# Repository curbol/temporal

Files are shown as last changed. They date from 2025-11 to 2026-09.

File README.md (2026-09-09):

# Temporal



A 36-42 key split ergonomic keyboard with wireless support, a breakoff pinky column, and optional encoders in the thumb cluster.

Temporal Preview

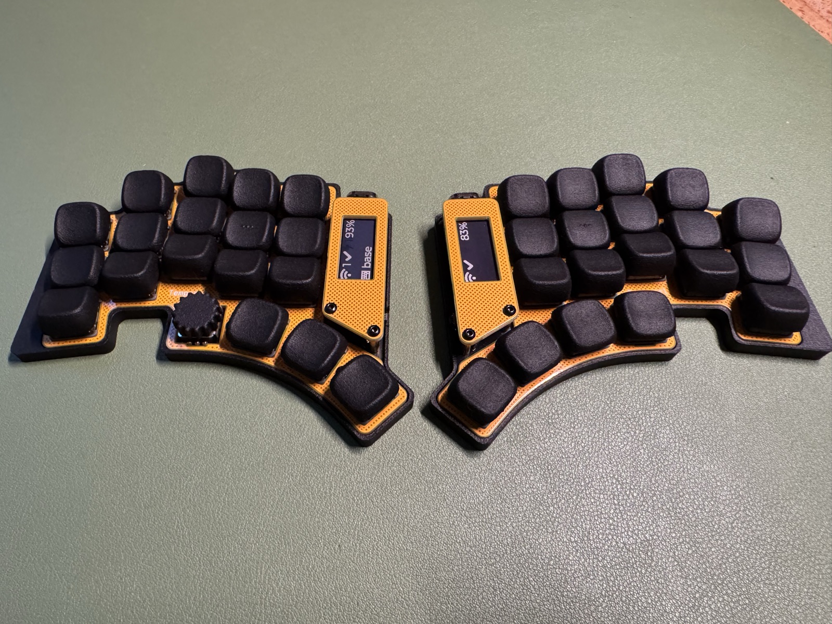
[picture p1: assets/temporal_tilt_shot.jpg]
Temporal tilt shot

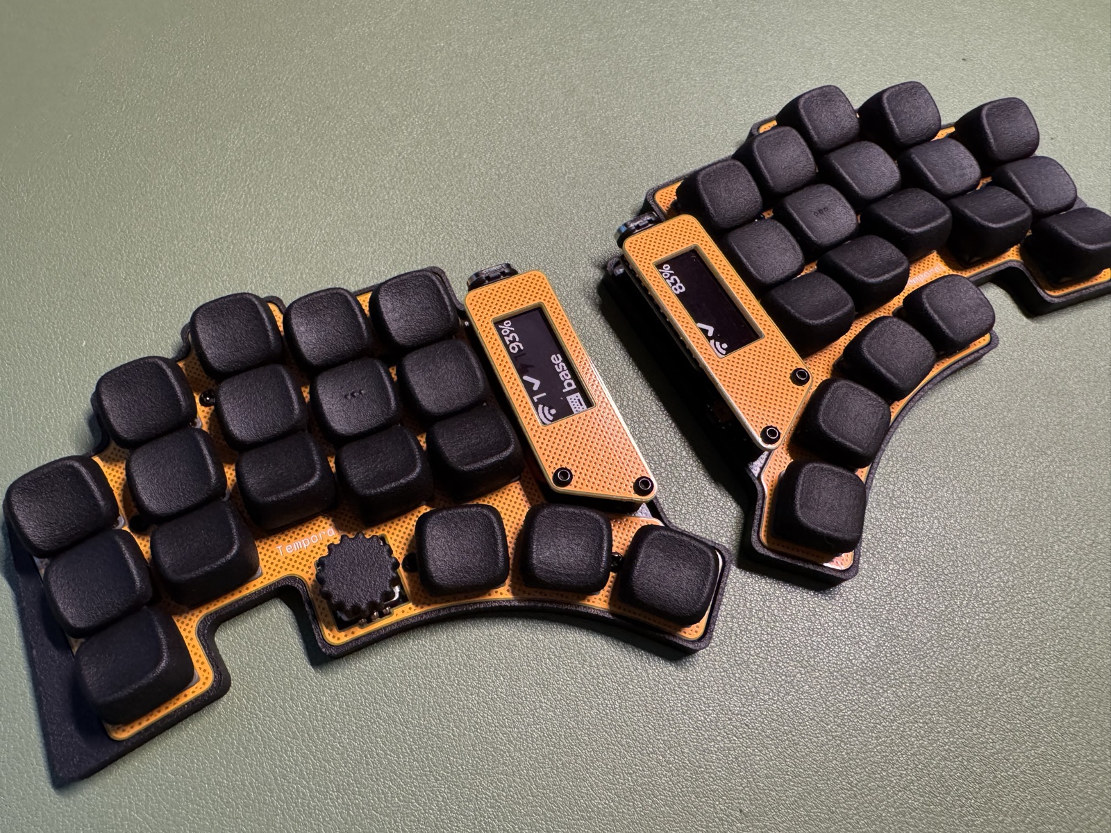
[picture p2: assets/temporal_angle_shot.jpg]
Temporal angle shot


## Design

### Layout

- 36-42 keys depending on configuration:
  - 42/41/40 keys (0/1/2 encoders) with full pinky column
  - 38/37/36 keys (0/1/2 encoders) with breakoff pinky column
- Column stagger and splay on pinky and ring columns

### Hardware

- Kailh Choc v1 or v2 low-profile switches, with optional hotswap sockets
- nice!nano or other Pro Micro compatible microcontrollers
- Optional nice!view display
- Optional EC11/EC12 rotary encoders in thumb cluster (up to 2)
- Wireless with battery support
- Reversible PCB
- 3D-printable cases, with an optional kickstand for tenting

### Tools

- [Ergogen](https://ergogen.ceoloide.com/) generates the layout, PCB, plates, and cases from [ergogen/config.yaml](ergogen/config.yaml)
- [KiCad](https://www.kicad.org/) v10 holds the hand-routed traces; its `pcbnew` API and `kicad-cli` drive the scripted post-processing and the exports

## Firmware

Temporal runs [ZMK](https://zmk.dev/). The shield definition and default keymap live in [temporal-zmk](https://github.com/curbol/temporal-zmk); [curbol/zmk-config](https://github.com/curbol/zmk-config) is a working config that uses it.

## Build Guide

[docs/build-guide.md](docs/build-guide.md) covers assembly and ordering. [docs/bom.md](docs/bom.md) lists every component a full build needs.

## Keycaps

Any Choc-compatible keycap fits. [KLP Lame Keycaps](https://github.com/braindefender/KLP-Lame-Keycaps) are 3D-printable and sculpted; [docs/bom.md](docs/bom.md#switches--keycaps) lists the print quantities for a full build.

## Development

### Prerequisites

- Node.js and npm
- A package manager `make deps` can drive: [Homebrew](https://brew.sh/) on macOS, or `pacman` and `yay` on Arch Linux

### Setup

1. Install dependencies (OpenSCAD, KiCad, zip/unzip, [Maple Mono NF](https://github.com/subframe7536/maple-font) font, and KiCad plugins):

```bash
make deps
```

2. Generate PCBs and cases:

```bash
make gen
```

This will:

- Run Ergogen to generate PCB and case files
- Derive `temporal.json`, the ZMK Studio physical layout, from the same points
- Post-process PCBs (edge cuts, silkscreen widths, ground planes, text keepouts,
  via stitching, zone fills, embedded fonts)
- Configure KiCad project files with defaults from `scripts/kicad_config.yaml`
- Derive the `top_plate_*_stealth` variants from the generated top plates
- Render `assets/preview.svg` and a `pcb.png` per board
- Export gerbers for manufacturing
- Generate the JLCPCB BOM and CPL files in `jlcpcb/`
- Generate STL case files

**Note:** The main `pcbs/temporal/` PCB requires manual steps in KiCad after generation. See [pcbs/temporal/README.md](pcbs/temporal/README.md) for details.

### Verifying

```bash
make check
```

Confirms the sources parse and lint, `ergogen/config.yaml` builds, every committed board passes DRC and carries its own silkscreen font, and the pours in `pcbs/` still match the custom DRC rules and the zone settings. It then regenerates each committed derived artifact and diffs it against what is checked in: `temporal.json`, `jlcpcb/`, the `.kicad_pro` and `.kicad_dru` files, the `top_plate_*_stealth` boards, and the gerber zips. This is what CI runs on every push.

## Influences

Temporal takes influence from:

- [Hillside](https://github.com/mmccoyd/hillside) by mmccoyd
- [TOTEM](https://github.com/GEIGEIGEIST/TOTEM) and [KLOR](https://github.com/GEIGEIGEIST/KLOR) by GEIST
- [TEMPEST](https://github.com/thrly/tempest) by thrly

## Support



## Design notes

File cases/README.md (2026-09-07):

# Cases

3D-printable parts. The STLs here are generated from
[`ergogen/config.yaml`](../ergogen/config.yaml) by `make gen`; edit the config, not
these files. This README is the one thing in the folder `make clean` keeps.

```
cases/
├── mcu_cover.stl
├── 38/
│   ├── top_plate.stl
│   ├── left.stl            right.stl
│   └── kickstand_left.stl  kickstand_right.stl
└── 42/                     (same layout)
```

## What to print

| part | quantity | notes |
|---|---|---|
| `NN/left.stl` and `NN/right.stl` | 1 each | the case halves, or the `kickstand_` pair instead |
| `NN/top_plate.stl` | 2 | one file, printed twice and flipped for the second hand |
| `mcu_cover.stl` | 2 | shared by both key counts |

`NN` is your key count: `42` if you keep the full pinky column, `38` if you snap it off.
A `42` case also fits the 41 and 40-key encoder configurations, and a `38` case the 37
and 36. Print the plain pair or the `kickstand_` pair, not both; the kickstand is a wedge
fused to the case for tenting.

[The build guide](../docs/build-guide.md#choose-your-build) walks through this alongside
the PCB and plate choices, and [docs/bom.md](../docs/bom.md) lists the hardware.

## One case, every build

There is no variant to choose. The case carries the clearances for all four switch and
mounting combinations at once:

- Choc v1 centre and side posts
- the Choc v2 centre boss and its corner stabilizer pin
- hotswap sockets, which stand 1.95mm off the back of the PCB
- the pins of switches soldered straight to the board

The floor is 2.35mm, which is the socket depth plus a 0.4mm skin. That makes every one
of those pockets blind, so the bottom face is solid and none of them shows through.

Print the halves bottom-down. Every pocket opens upward, so nothing needs support.

## FR-4 alternative

The top plate and MCU cover also exist as orderable PCBs
([`gerbers/`](../gerbers/)), and there is an FR-4 back plate that replaces the printed
case entirely, held off the board by 3mm standoffs. See
[the build guide](../docs/build-guide.md#fr-4-plate-alternative).

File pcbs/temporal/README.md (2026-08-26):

# Temporal PCB

`make gen` never overwrites this directory.

## Why

This board is hand-routed in KiCad, and the traces and vias here cannot be
regenerated. The build leaves the `.kicad_pcb` alone and rewrites only the
`.kicad_pro` and `.kicad_dru` beside it.

## How to Regenerate

Delete the folder, then rebuild:

```bash
rm -rf pcbs/temporal
make gen
```

That recreates the directory and a fresh, unrouted board from
`ergogen/config.yaml`.

## Manual Steps in KiCad

After regenerating, route the connections Ergogen does not place. Ground planes,
silkscreen text keepouts, via stitching, and zone fills are all applied by
`make gen` before the board is copied here, so they need no manual work.

## Keeping This Board Current

The post-processing steps run against `ergogen/output/pcbs`, so they reach this
board only when it is regenerated. Editing the `zones`, `via_stitching`, or
`text_keepouts` sections of `scripts/kicad_config.yaml` updates every other board
and leaves this one as it was. `make check` fails when the pour no longer matches
the custom DRC rules; a via stitching or keepout change needs a full regeneration
and a re-route.

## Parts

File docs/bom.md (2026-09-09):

# Bill of Materials (BOM)

Everything needed to build one Temporal keyboard, both halves.

## Required Components

### Electronics

| Component | Quantity | Notes | Source | Image |
|---|---|---|---|---|
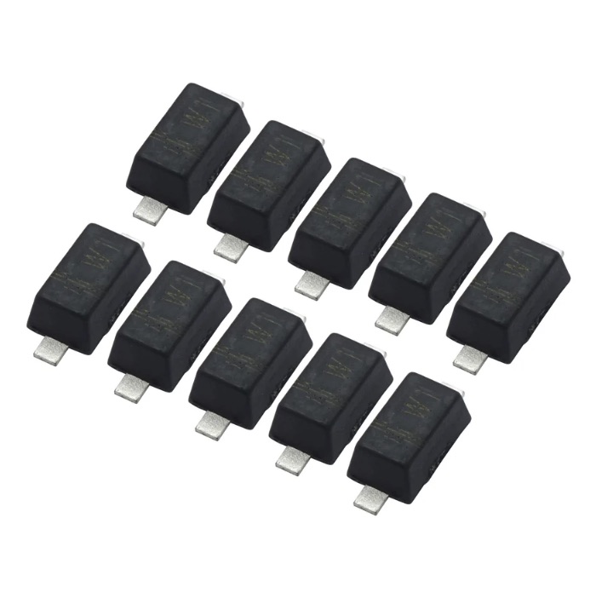
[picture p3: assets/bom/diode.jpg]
SMD diode
| SMD Diodes (1N4148W) | 36-42 | One per switch, depends on configuration (not needed if using JLCPCB assembly) | [KEEBD](https://keebd.com/) [Typeractive](https://typeractive.xyz/) |  |
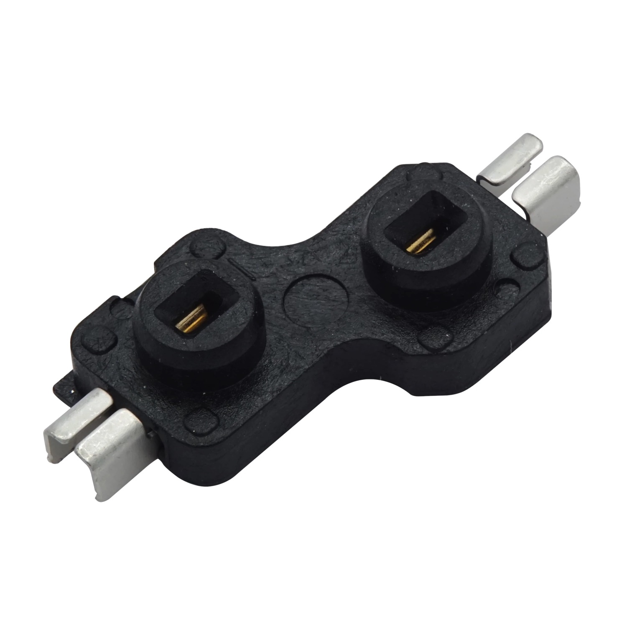
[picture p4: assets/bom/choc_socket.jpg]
Choc socket
| Kailh Choc Hotswap Sockets | 36-42 | Optional; allows switch swapping without desoldering | [KEEBD](https://keebd.com/) [Typeractive](https://typeractive.xyz/) |  |
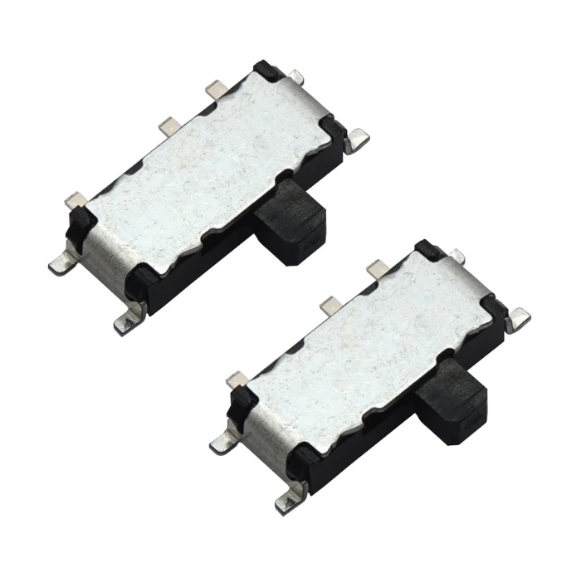
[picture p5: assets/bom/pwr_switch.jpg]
Power switch
| Power Switch (MSK12C02) | 2 | Power on/off switch | [KEEBD](https://keebd.com/) [Typeractive](https://typeractive.xyz/) |  |
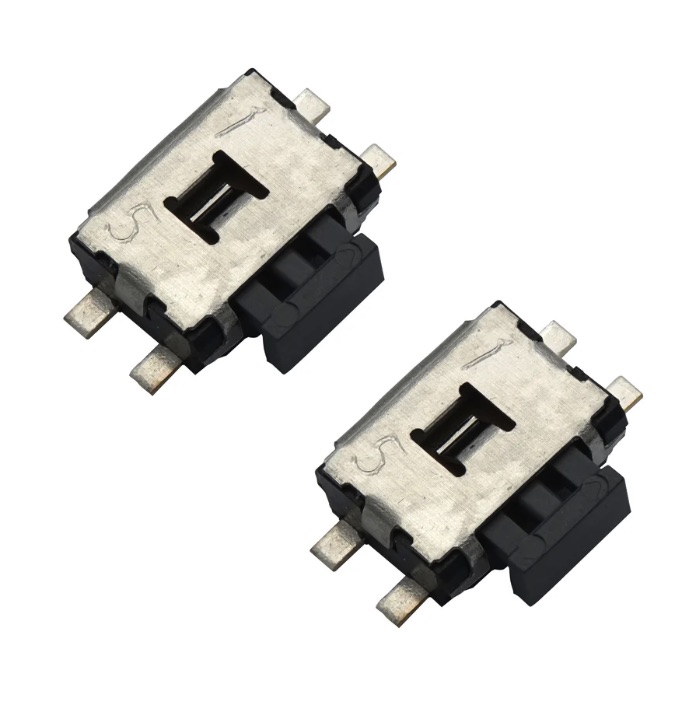
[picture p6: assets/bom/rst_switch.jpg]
Reset switch
| Reset Button (3x6x4.3mm) | 2 | SMD tactile switch | [KEEBD](https://keebd.com/) [Typeractive](https://typeractive.xyz/) |  |
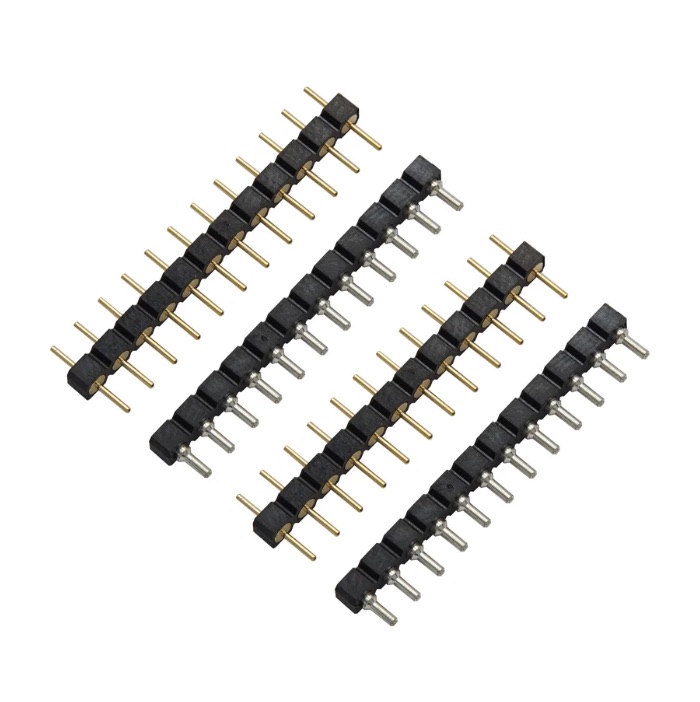
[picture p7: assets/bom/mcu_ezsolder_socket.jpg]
EZ-Solder sockets
| EZ-Solder Machine Sockets and Headers | 2 sets | For nice!nano installation | [KEEBD](https://keebd.com/) [Typeractive](https://typeractive.xyz/) |  |
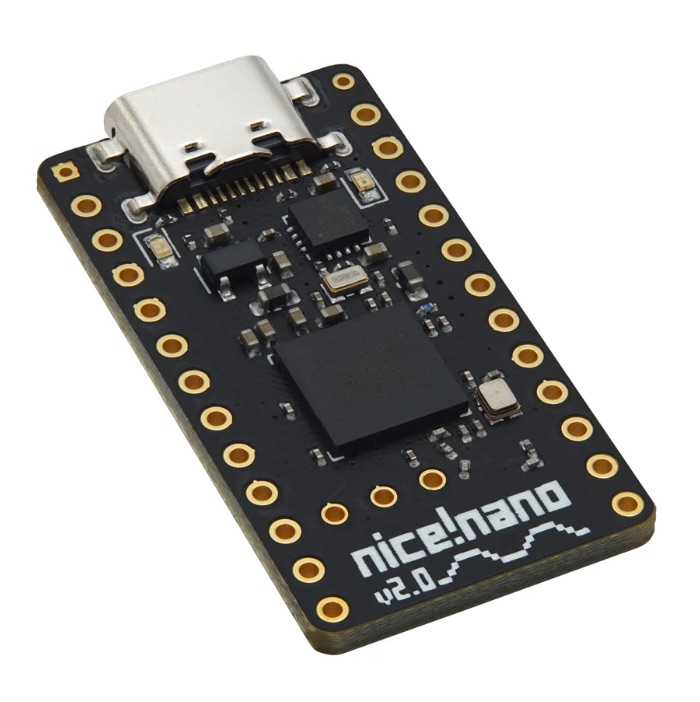
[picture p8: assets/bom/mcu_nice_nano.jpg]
nice!nano
| nice!nano v2.0 | 2 | Wireless microcontroller | [KEEBD](https://keebd.com/) [Typeractive](https://typeractive.xyz/) |  |
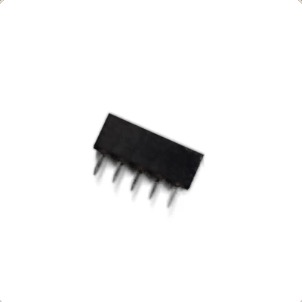
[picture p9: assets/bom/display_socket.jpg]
Display socket
| Display Header Socket (5-pin 2.54mm) | 2 | If your display doesn't already come with the correct header | [KEEBD](https://keebd.com/) [Typeractive](https://typeractive.xyz/) |  |
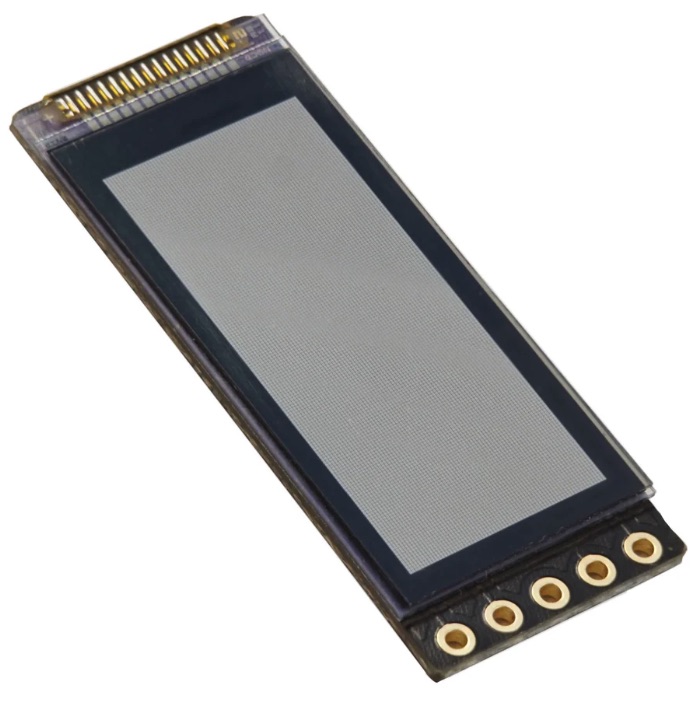
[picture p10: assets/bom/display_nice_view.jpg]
nice!view
| nice!view | 2 | Optional display | [KEEBD](https://keebd.com/) [Typeractive](https://typeractive.xyz/) |  |
| Battery Jack (JST PH 2.0mm) | 2 | For battery connection | [KEEBD](https://keebd.com/) [Typeractive](https://typeractive.xyz/) | Battery connector |
| Lithium Battery 110mAh | 2 | PH 2.0mm connector (or similar capacity) | [KEEBD](https://keebd.com/) [Typeractive](https://typeractive.xyz/) | Battery |
| ALPS EC11/EC12 Rotary Encoder | 0-2 | Optional, for thumb key encoder positions | [KEEBD](https://keebd.com/en-us/collections/components) | Encoder |
| Low Profile Knurled Encoder Knob | 0-2 | If using encoders | [KEEBD](https://keebd.com/en-us/collections/components) | Encoder knob |

Encoders and hotswap sockets are both optional: regular switches work in the encoder positions, and switches can be soldered straight to the PCB.

### Hardware

| Component | Quantity | Notes | Source | Image |
|---|---|---|---|---|
| M2 Heat-Set Inserts | 10 | 3mm OD × 3mm height (2mm height also works) | [KEEBD](https://keebd.com/) | Heat-set insert |
| M2 Screws (4mm length) | 18 | Button-head recommended | Amazon | M2 screw |
| M2 Standoffs (8mm length) | 4 | For MCU cover mounting | [KEEBD](https://keebd.com/) Amazon | M2 standoff |
| M2 Standoffs (3mm length) | 10 | FR-4 plate build only, in place of the heat-set inserts | Amazon | |
| M2 Screws (3mm length) | 20 | FR-4 plate build only, button-head | Amazon | |

Avoid inserts wider than 3mm OD. A 3.2mm insert may not seat in the case posts.

### Switches & Keycaps

| Component | Quantity | Notes | Source | Image |
|---|---|---|---|---|
| Choc v1 or v2 Switches | 36-42 | Low-profile switches, depends on configuration | [Low Pro KB](https://lowprokb.ca/) [KEEBD](https://keebd.com/en-us/collections/choc-switches) | Choc switch |
| Choc Keycaps | 36-42 | Compatible with Choc switches | | |

[Ambients Silent Choc switches](https://lowprokb.ca/collections/switches/products/ambients-silent-choc-switches) are my pick for a quiet, smooth feel. Sculpted keycaps improve the feel more than anything else on this page, though that is personal preference.

[KLP Lame Keycaps](https://github.com/braindefender/KLP-Lame-Keycaps) are 3D-printable sculpted keycaps for Choc switches. Ordered from a printing service, a full Temporal build needs:

| Part | Quantity | Contents |
|---|---|---|
| Saddle part 1 | 1 | 6 tilted, 3 saddle |
| Saddle part 2 | 2 | 4 tilted, 4 saddle, 1 homing |
| Saddle part 3 | 1 | 9 tilted |
| Thumbs | 1 | 9 thumbs |

Totals: 23 tilted, 11 saddle, 2 homing, and 9 thumb, of which 6-8 are used depending on encoders.

### PCBs & Cases

| Component | Quantity | Notes |
|---|---|---|
| Temporal PCB | 2 | Order using `gerbers/temporal.zip` |
| 3D-Printed Case (Left) | 1 | Choose your key configuration and switch mounting (see below) |
| 3D-Printed Case (Right) | 1 | Choose your key configuration and switch mounting (see below) |
| MCU Cover | 2 | Optional, protects the microcontroller |

Use [`gerbers/temporal.zip`](/gerbers/temporal.zip) for PCB fabrication with services like JLCPCB or PCBWay.

- Material: FR-4, 1.6mm thickness
- Surface finish: LeadFree HASL
- See [`pcbs/temporal/README.md`](/pcbs/temporal/README.md) for notes on the hand-routed main PCB

> [!TIP]
> Top plates, back plates, and MCU covers can be ordered in HASL (with lead) instead of LeadFree HASL. It is usually cheaper, and these parts have no exposed copper pads, so the finish does not matter.

> [!TIP]
> Order top plates at 1.2mm thickness instead of 1.6mm for the best fit with Choc switches.

3D-printable case files are in the [`cases/`](/cases/) directory, foldered by key count:

```
cases/
├── mcu_cover.stl
├── 38/
│   ├── top_plate.stl
│   ├── left.stl            right.stl
│   └── kickstand_left.stl  kickstand_right.stl
└── 42/                     (same layout)
```

Pick your key count, then print the `left` and `right` pair, with or without the
kickstand. One case fits every build: Choc v1 or v2, hotswap sockets or switches
soldered straight to the board. It carries the clearances for all of them, and at a
2.35mm floor every pocket is blind, so the bottom face is solid.

- **`38` / `42`**: key configuration, matching the breakoff pinky column. A 42 case
  also takes the 41 and 40-key encoder configurations, and a 38 case the 37 and 36.
- **`kickstand`**: optional, adds a wedge for tenting.
- **`top_plate`**: one per hand, printed twice from the same file and flipped.
- **`mcu_cover`**: shared by both hands and both key counts, printed twice.

Top plates are also available as `top_plate_<38|42>_stealth` gerbers: the same plate
without the white silkscreen branding, leaving the lettering as an outline in the
ground plane.

**For home 3D printing:**

- Material: matte PLA
- Layer height: 0.12mm
- Infill: not critical, since the walls are thin

**For JLC's 3D printing service:**

- Technology: MJF (nylon)
- Material: PA11-HP nylon, verified to work well for cases and keycaps

> [!NOTE]
> Other materials likely print fine too; these are just the ones tested.

Alternatively, the gerbers in [`gerbers/`](/gerbers/) cover FR-4 switch plates you can order alongside your PCB: top plates, back plates, and MCU covers for every configuration.

## Optional Tools

| Tool | Purpose | Source | Image |
|---|---|---|---|
| NovelLife Heat-Set Insert Tool | Drives heat-set inserts with a soldering iron | Amazon | Heat-set insert tool |
| Flux Pen | Helps solder flow nicely, especially for jumpers | [KEEBD](https://keebd.com/en-us/products/kester-951-no-clean-solder-flux-pen) | Flux pen |

## Where to Buy

- [KEEBD](https://keebd.com/): nice!nano, nice!view, switches, sockets, encoders, and most other components
- [Typeractive](https://typeractive.xyz/): most of the same parts
- Amazon: heat-set inserts, screws, and general hardware
- AliExpress: cheaper on most components, with longer shipping

### PCB Manufacturing

- [JLCPCB](https://jlcpcb.com/): inexpensive, with an optional assembly service
- [PCBWay](https://www.pcbway.com/): the usual alternative

Use the gerber files in [`gerbers/`](/gerbers/) when ordering.

> [!TIP]
> Here is how JLCPCB's PCB colors look:
>
> PCB color options

#### JLCPCB Assembly (Optional)

JLCPCB can pre-assemble the SMD parts onto your PCBs:

- 21 diodes per board, so none of them need hand-soldering
- 30 0-ohm resistors per board, bridging the solder jumper pads for the MCU, display, and battery connections

To use this service:

1. Select "PCB Assembly" when ordering
2. Upload files from [`jlcpcb/`](/jlcpcb/):
   - `temporal_BOM.csv`: the bill of materials, with LCSC part numbers
   - `temporal_CPL_top.csv`: places parts on the top face, giving the **right**
     half (its top silkscreen reads "Back Right" above the MCU area)
   - `temporal_CPL_bottom.csv`: places parts on the bottom face, giving the
     **left** half ("Back Left")

You need one board of each hand, and assembly is ordered per side, so place two
orders, one per CPL file. A single order using one CPL gives you two identical
halves.

> [!NOTE]
> Hotswap sockets are not in the assembly files, so they still need hand-soldering.

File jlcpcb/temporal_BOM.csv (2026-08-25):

Comment | Designator | Footprint | LCSC Part #
0402 0-Ohm Resistor | JR1,JR10,JR11,JR12,JR13,JR14,JR15,JR16,JR17,JR18,JR19,JR2,JR20,JR21,JR22,JR23,JR24,JR25,JR26,JR27,JR28,JR29,JR3,JR30,JR4,JR5,JR6,JR7,JR8,JR9 | 0402 | C17168
1N4148W Diode SOD-123 | D1,D10,D11,D12,D13,D14,D15,D16,D17,D18,D19,D2,D20,D21,D3,D4,D5,D6,D7,D8,D9 | ceoloide:diode_tht_sod123 | C81598

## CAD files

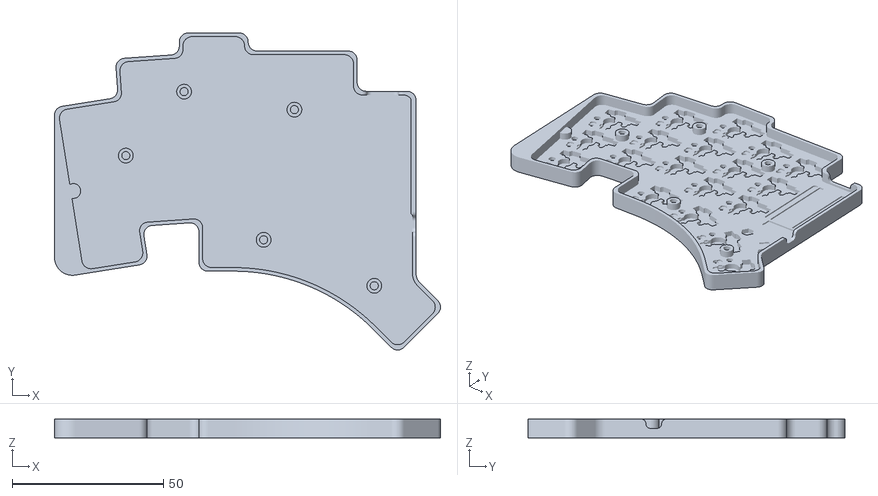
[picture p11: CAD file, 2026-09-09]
cases/38/kickstand_left.stl
127.5 x 104.7 x 6.25

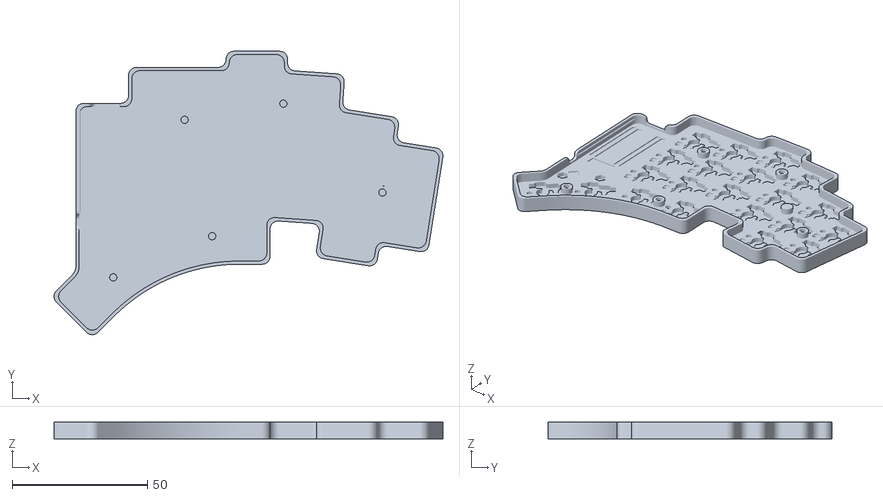
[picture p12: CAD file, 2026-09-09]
cases/42/right.stl
143.7 x 104.7 x 6.25

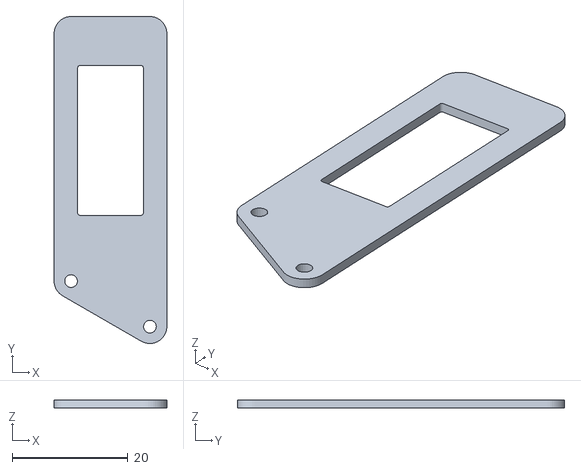
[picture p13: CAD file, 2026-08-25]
cases/mcu_cover.stl
19.4 x 56.4 x 1.30

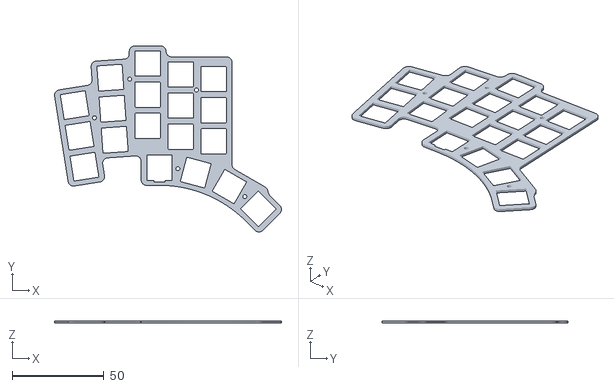
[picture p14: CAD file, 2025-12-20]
cases/top_plate_40_left.stl
124.0 x 101.6 x 1.30

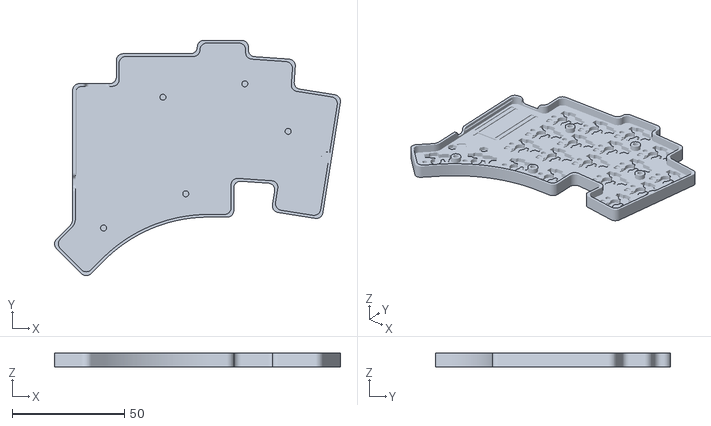
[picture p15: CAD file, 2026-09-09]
cases/38/right.stl
127.3 x 104.7 x 6.25

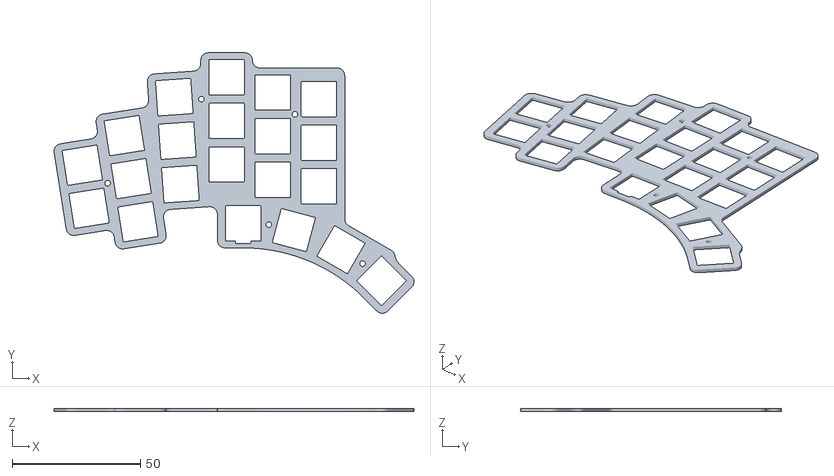
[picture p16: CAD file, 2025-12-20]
cases/top_plate_44_left.stl
140.4 x 101.6 x 1.30

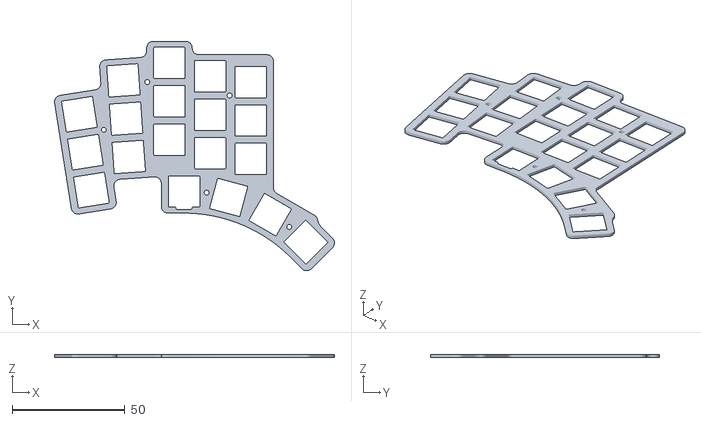
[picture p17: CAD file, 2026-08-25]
cases/38/top_plate.stl
124.0 x 101.6 x 1.30

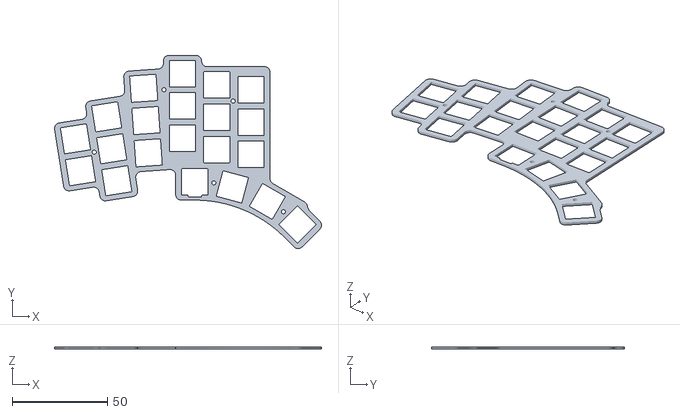
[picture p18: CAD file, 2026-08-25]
cases/42/top_plate.stl
140.4 x 101.6 x 1.30

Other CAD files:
cases/38/kickstand_right.stl
cases/42/kickstand_left.stl
cases/42/kickstand_right.stl
cases/mcu_cover_left.stl
cases/38/left.stl
cases/42/left.stl

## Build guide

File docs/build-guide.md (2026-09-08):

# Build Guide

Building a Temporal from bare PCBs to a flashed, working keyboard.

> [!TIP]
> [Typeractive's Corne wireless build guide](https://docs.typeractive.xyz/build-guides/corne-wireless) covers a similar board and has videos that may be helpful.

## Before You Start

### Choose Your Build

Four decisions settle everything you order and print. Only the first two change which
files you need; the switch generation and whether you socket or solder are yours to make
at assembly time, because one case covers all of them.

```mermaid
flowchart TD
    A["Full pinky column?"] -->|"Keep it: 40-42 keys"| B42["42"]
    A -->|"Snap it off: 36-38 keys"| B38["38"]
    B42 --> C{"Top plate and back:<br/>printed or FR-4?"}
    B38 --> C
    C -->|"3D printed"| P["Order temporal.zip<br/><br/>Print from cases/NN/:<br/>left.stl + right.stl<br/>top_plate.stl x2<br/><br/>Print from cases/:<br/>mcu_cover.stl x2"]
    C -->|"FR-4 plates"| F{"Silkscreen branding<br/>on the top plate?"}
    F -->|"Keep it"| F1["Order temporal.zip<br/>top_plate_NN.zip<br/>back_plate_NN.zip<br/>mcu_cover.zip"]
    F -->|"Stealth"| F2["Order temporal.zip<br/>top_plate_NN_stealth.zip<br/>back_plate_NN.zip<br/>mcu_cover.zip"]
    P --> K{"Tenting kickstand?"}
    K -->|"Yes"| K1["Print kickstand_left.stl<br/>+ kickstand_right.stl<br/>instead of left/right"]
    K -->|"No"| K2["Done"]
```

Gerber zips are in [`gerbers/`](/gerbers/); `NN` is your key count. Every build needs
`temporal.zip`, which is the main PCB, twice. [docs/bom.md](/docs/bom.md) lists the
components.

One 3D-printed case fits every switch and mounting combination: it carries the pockets
for Choc v1 posts, the Choc v2 centre boss and stabilizer pin, hotswap sockets, and
directly soldered switch pins all at once. At a 2.35mm floor they are all blind, so the
bottom face is solid whichever build you do.

### Key Configuration

Decide on your key configuration (36-42 keys) first. The outer pinky columns snap off the PCB if you do not want them, and each encoder replaces one key position in the thumb cluster.

**Available configurations:**

- **With full pinky column:** 42 keys, 41 keys + 1 encoder, or 40 keys + 2 encoders
- **With breakoff pinky column:** 38 keys, 37 keys + 1 encoder, or 36 keys + 2 encoders

**To remove the pinky column:**

1. Lay the PCB on a hard flat surface with the extra column hanging off the edge
2. Press down on the main PCB to hold it steady
3. Snap off the extra column by pushing down on it quickly and forcefully
4. Sand the PCB edge flat using sandpaper on a flat surface (200-400 grit works well)
5. Clean up thoroughly to remove any PCB dust and residue

> [!WARNING]
> PCB dust is toxic. Wear a mask and work in a well-ventilated area or outside. Clean up well after sanding.

### Identify Left and Right PCBs

The Temporal PCBs are reversible. Before soldering, decide which PCB will be left and which will be right. Components are soldered to opposite sides of each PCB. Look for "Back Left" or "Back Right" printed above the MCU area to confirm you're working on the correct side.

> [!CAUTION]
> Double-check your orientation before soldering. Building two of the same side is a common mistake that's difficult to fix.

### Tools Needed

- Soldering iron with fine tip
- Solder (leaded solder is easier to work with)
- Tweezers
- Flush cutters / wire snips
- Kapton tape or masking tape
- Heat-set insert tool (optional, for the 3D-printed case)

---

## Assembly Overview

Follow this general order:

1. Back side: diodes, hotswap sockets, jumpers
2. Front side: power switch, reset button
3. Front side: MCU sockets, display header, battery connector
4. Front side: encoder, if you are fitting one
5. Microcontroller and display, then clean the PCB
6. Case assembly
7. Switches and keycaps

---

## Step 1: Solder Back Components

All components in this step are soldered to the **back side** of the PCB.

### Soldering Technique

For SMD components (diodes, sockets, jumpers), use this technique:

1. Apply a small amount of solder to **one pad only**
2. Using tweezers, position the component while heating the pre-soldered pad
3. The component sinks into the molten solder; hold it in place until the solder solidifies
4. Solder the remaining pad(s), touching both the pad and component lead simultaneously

### Diodes

> [!NOTE]
> If the diodes are already installed using JLCPCB assembly, skip this step.

Install one diode per key position, 18-21 per half depending on your configuration. Diodes are directional: the line on the diode must match the line on the PCB silkscreen.

1. Pre-tin one pad of each diode location
2. Place the diode with the line matching the PCB marking
3. Heat the pre-tinned pad while holding the diode with tweezers
4. Solder the second pad

### Hotswap Sockets

Install one socket per key position, matching your diode count. Sockets fit one way only: line the chamfered corners up with the silkscreen outline.

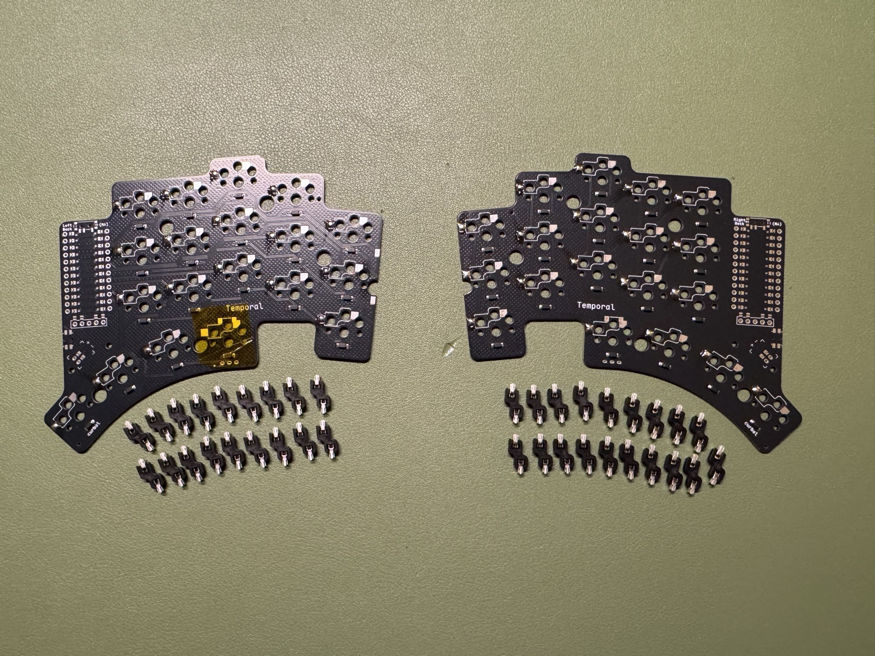
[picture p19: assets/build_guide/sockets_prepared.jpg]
Hotswap sockets prepared


1. Pre-tin one pad
2. Place the socket in the silkscreen outline
3. Heat and position the socket
4. Solder the second pad, using enough solder for a solid connection

> [!TIP]
> Apply gentle pressure while soldering to ensure the socket sits flat against the PCB.

> [!TIP]
> Install sockets in the encoder positions even if you are fitting encoders. They do not interfere, and leaving the position socketed keeps the option of a plain switch there later.

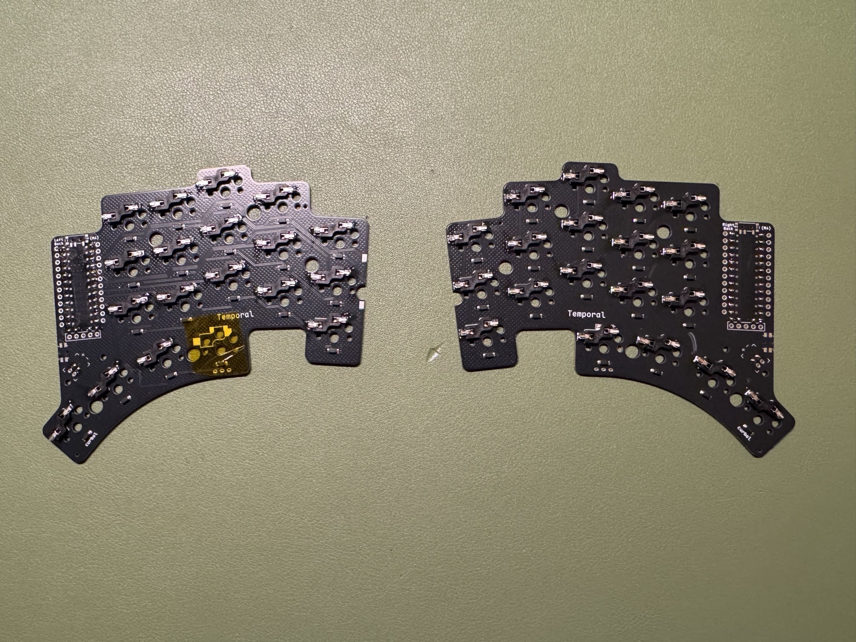
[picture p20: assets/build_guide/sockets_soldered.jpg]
Hotswap sockets soldered


> [!NOTE]
> Hotswap sockets are optional. Soldering switches straight to the PCB saves their cost, at the price of desoldering to change a switch later.

### Jumpers

> [!NOTE]
> If the jumpers are already bridged with 0-ohm resistors from JLCPCB assembly, skip this step.

> [!IMPORTANT]
> Only bridge jumpers on the **BACK side** of the board. This is the same side as your diodes and hotswap sockets.

Bridge all jumper pads on the back side. There are jumpers for the MCU, display, and battery connections.

1. Apply solder to one pad
2. Add more solder while dragging across to the second pad to create a bridge
3. The bridge should be a smooth dome of solder connecting both pads

---

## Step 2: Solder Power and Reset Switches

These components are soldered to the **front side** of the PCB.

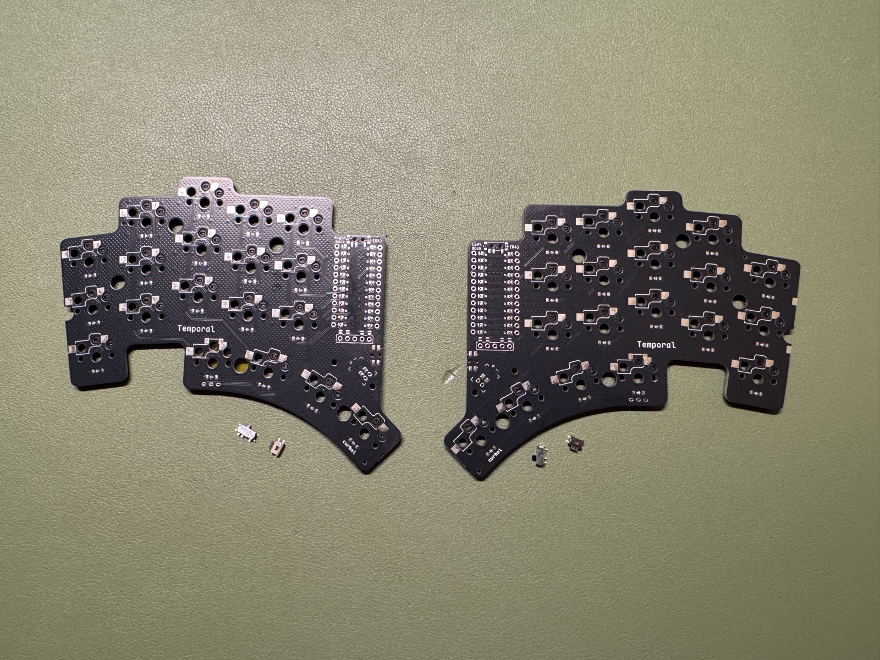
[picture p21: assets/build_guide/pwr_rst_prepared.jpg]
Power and reset switches prepared


### Power Switch (MSK12C02)

> [!TIP]
> These components have multiple legs; once one is tacked down, the rest are easy.

1. Pre-tin one of the pads
2. Position the switch and heat the pre-tinned pad while holding the switch in place with tweezers
3. Solder the remaining pads

### Reset Button

1. Pre-tin one pad
2. Align the button and heat the pre-tinned pad
3. Solder the remaining pads

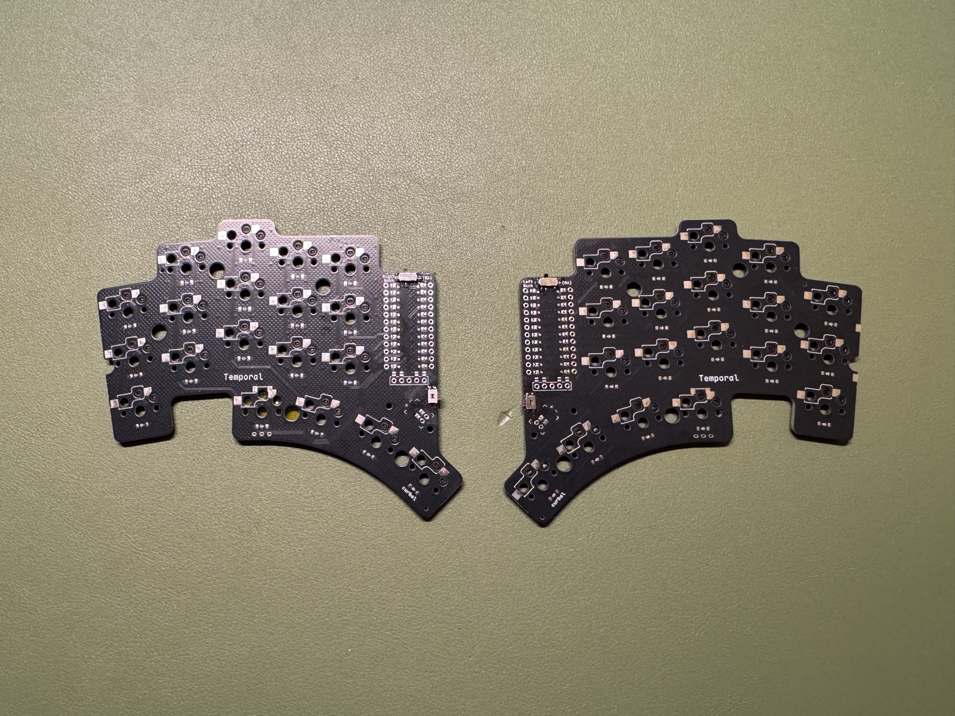
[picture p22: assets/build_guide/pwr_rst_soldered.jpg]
Power and reset switches soldered


---

## Step 3: Solder MCU, Display, and Battery Components

These components are installed on the **front side** of the PCB. The sockets and headers use through-hole pins that are soldered from the back.

> [!TIP]
> For all through-hole components: after tacking two corner pins, verify the component is straight and fully seated before soldering the rest.

### MCU Sockets

> [!IMPORTANT]
> The microcontroller will be placed **facing DOWN** (components facing the PCB). Ensure your sockets are positioned correctly.

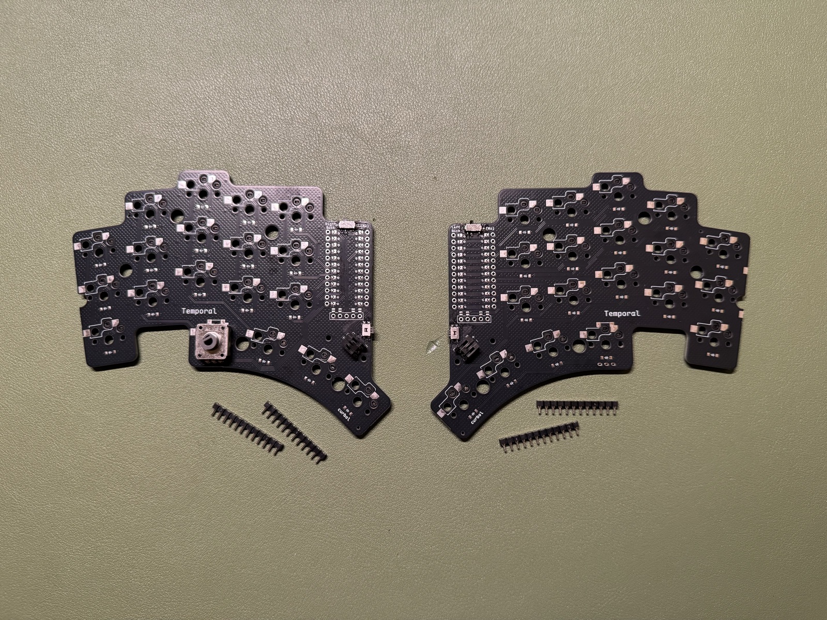
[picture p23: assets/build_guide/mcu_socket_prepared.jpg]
MCU sockets prepared


1. Insert the sockets into the front of the PCB
2. Tape them in place to prevent them from falling out when you flip the board

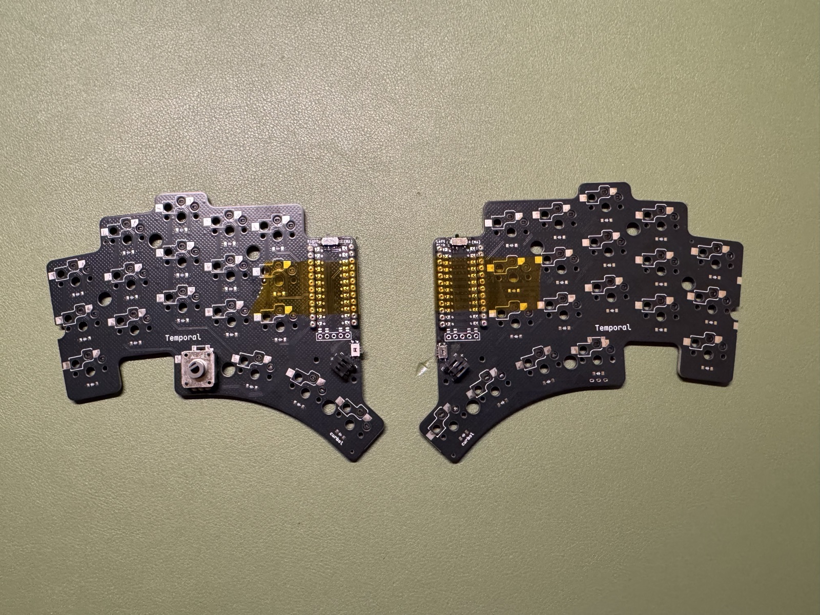
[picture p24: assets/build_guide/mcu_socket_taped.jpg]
MCU sockets taped


3. Flip the PCB and solder two pins on opposite corners first while pressing the socket flat against your work surface to ensure it's fully seated
4. Solder the remaining pins
5. Trim the pins flush with the solder joints using wire snips

### Display Header

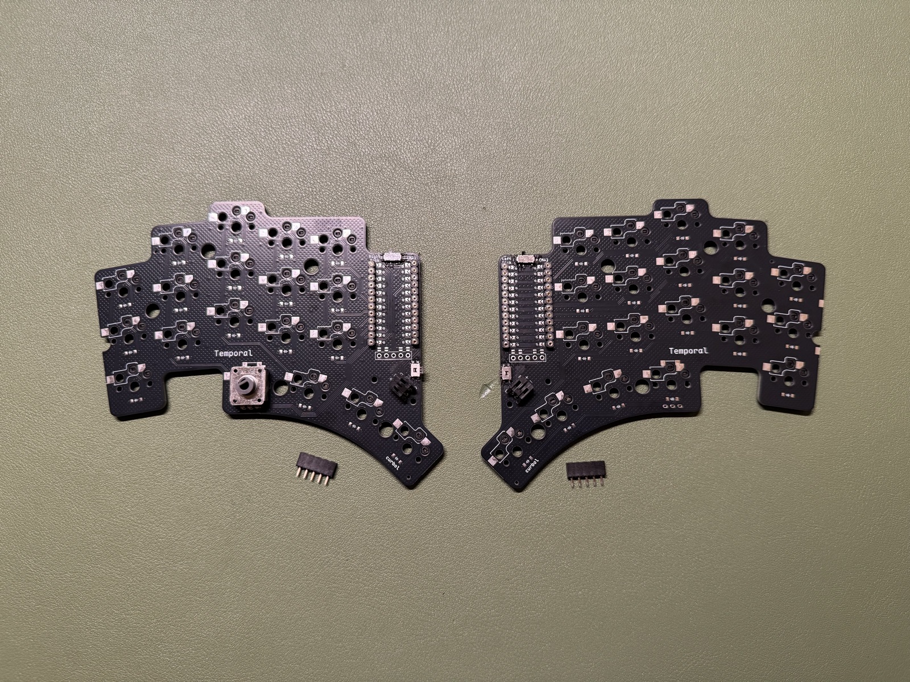
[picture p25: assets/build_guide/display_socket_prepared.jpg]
Display header prepared


1. Insert the header pins into the front of the PCB
2. Tape in place

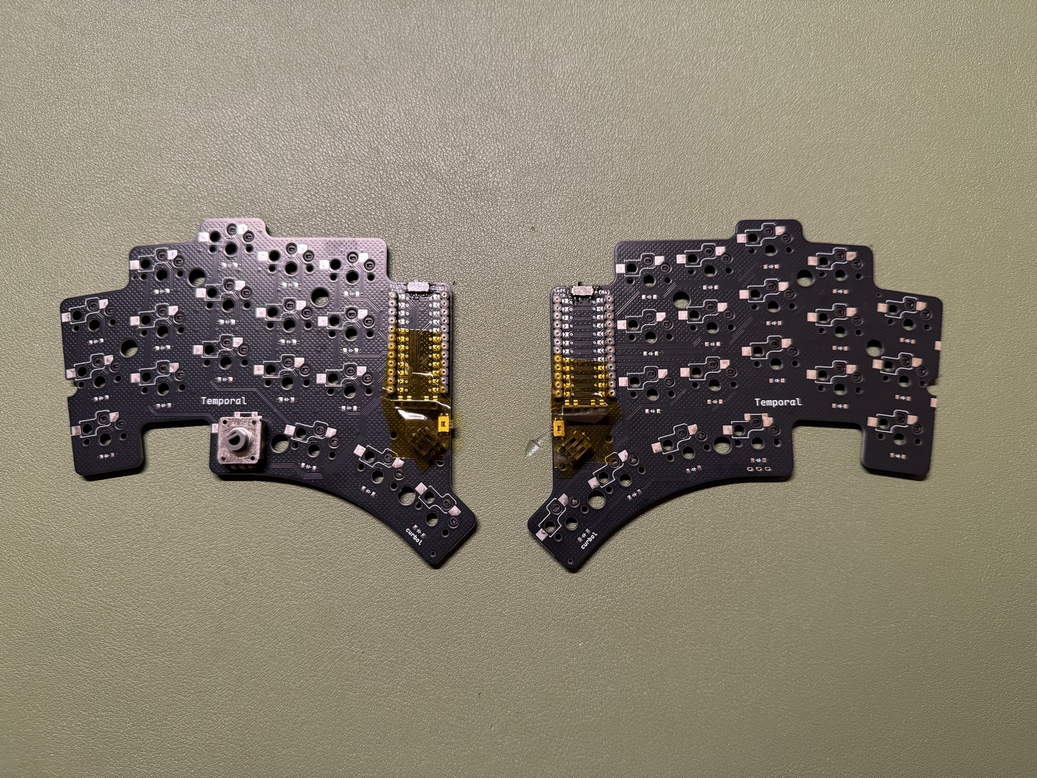
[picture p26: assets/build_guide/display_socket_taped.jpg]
Display header taped


3. Solder from the back using the same technique as the MCU sockets

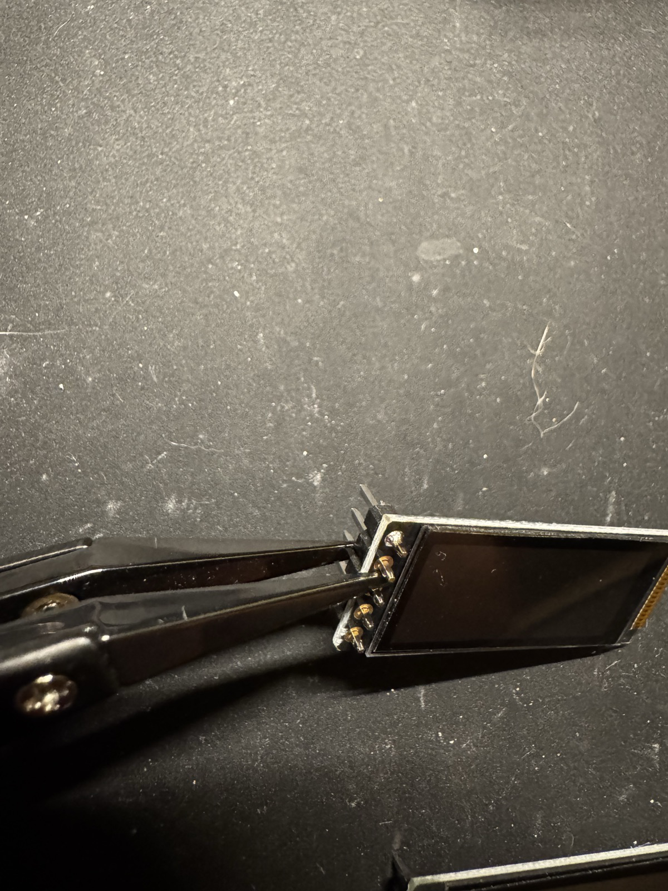
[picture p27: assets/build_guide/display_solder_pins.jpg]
Display header pins soldered


4. Trim the pins

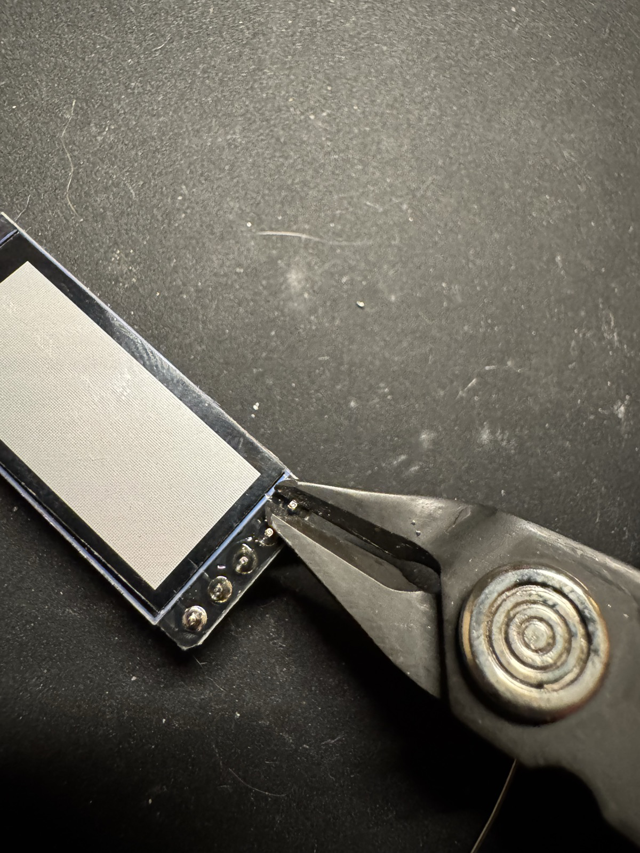
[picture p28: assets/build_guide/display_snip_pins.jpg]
Display header pins trimmed


### Battery Connector

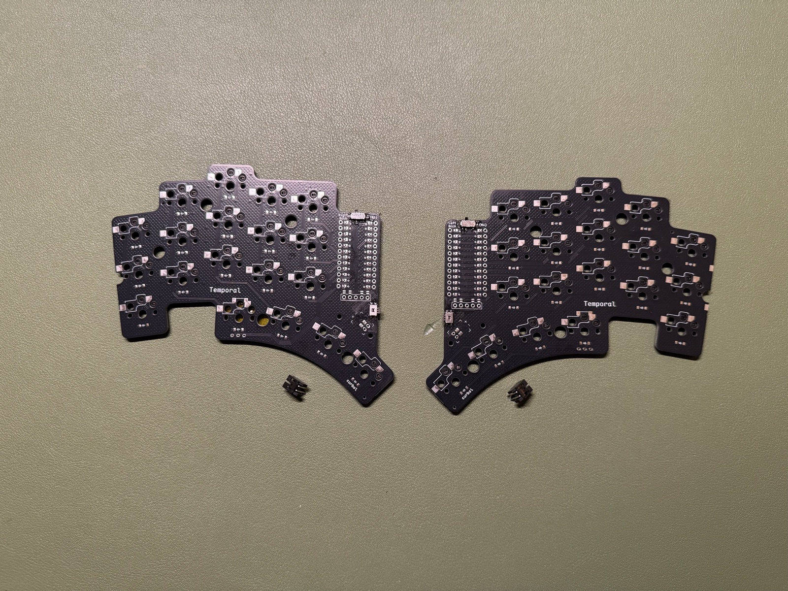
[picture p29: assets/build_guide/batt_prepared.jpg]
Battery connector prepared


1. Insert the connector into the front of the PCB
2. Tape in place

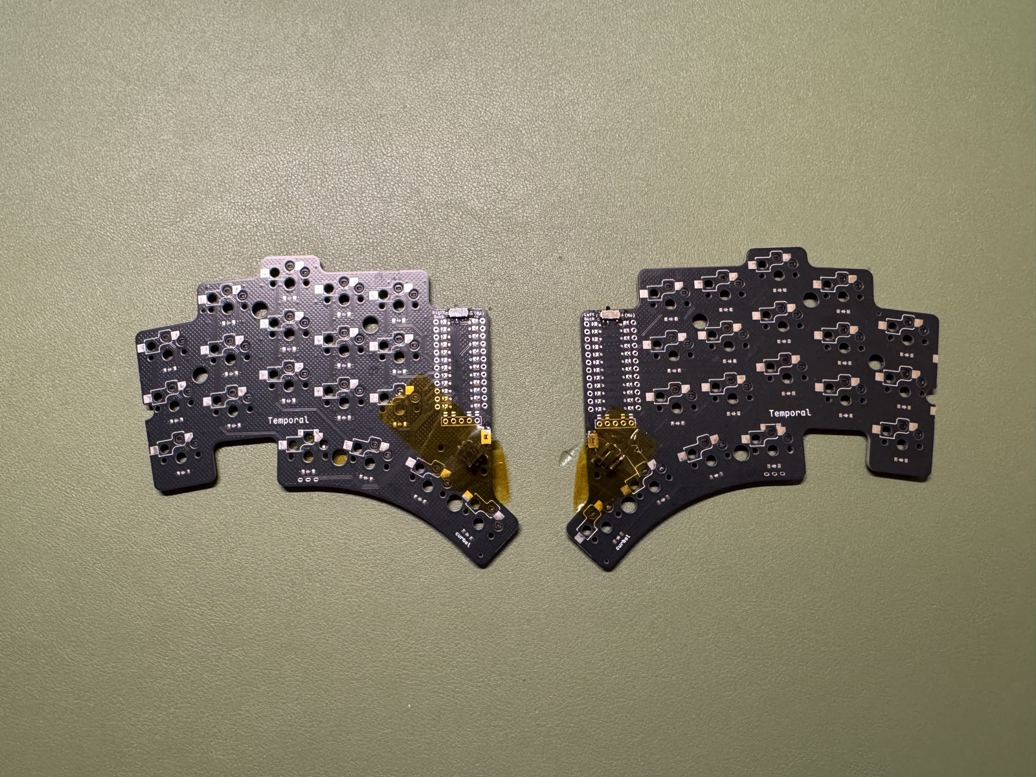
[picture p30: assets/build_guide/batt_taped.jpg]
Battery connector taped


3. Solder from the back
4. Trim the pins

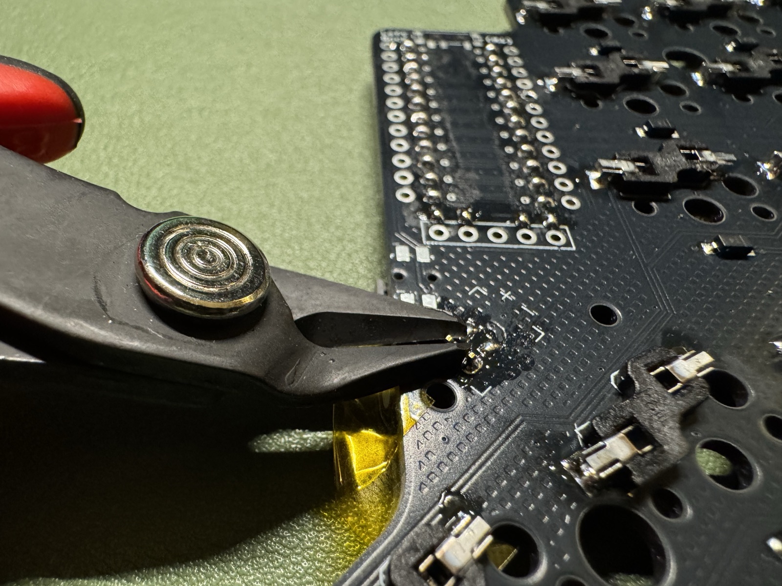
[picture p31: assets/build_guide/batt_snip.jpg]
Battery connector pins trimmed


> [!IMPORTANT]
> When connecting the battery later, verify polarity matches the PCB markings (+ and -). Reversed polarity can damage the microcontroller. Most 301230 or 401230 LiPo batteries with JST connectors work well.

---

## Step 4: Solder Encoder (Optional)

If you're using rotary encoders instead of switches in the thumb cluster positions:

### Encoder Installation

The encoder has side clips that snap into the PCB, so taping is not necessary.

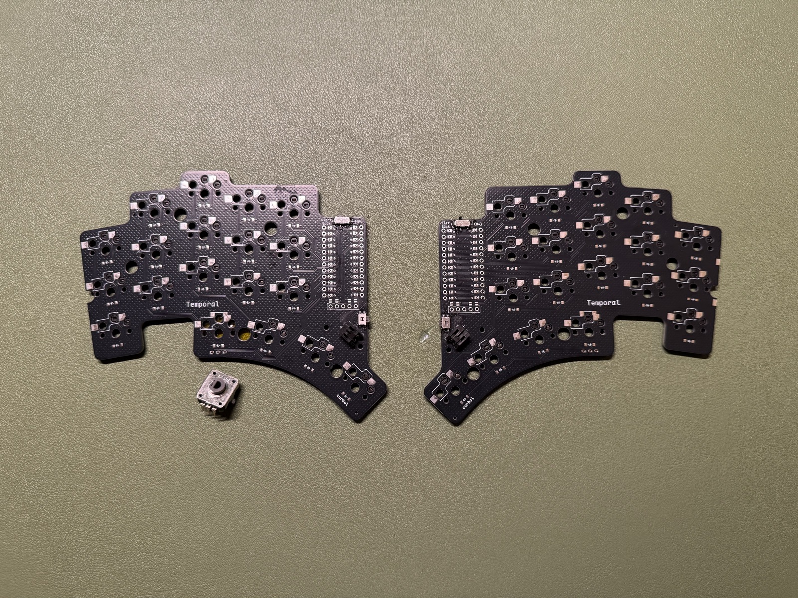
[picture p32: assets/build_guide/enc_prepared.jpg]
Encoder prepared


1. Insert the encoder from the front; the clips snap into the mounting holes
2. Flip the board and solder the 3 encoder pins on the back
3. Trim the pins

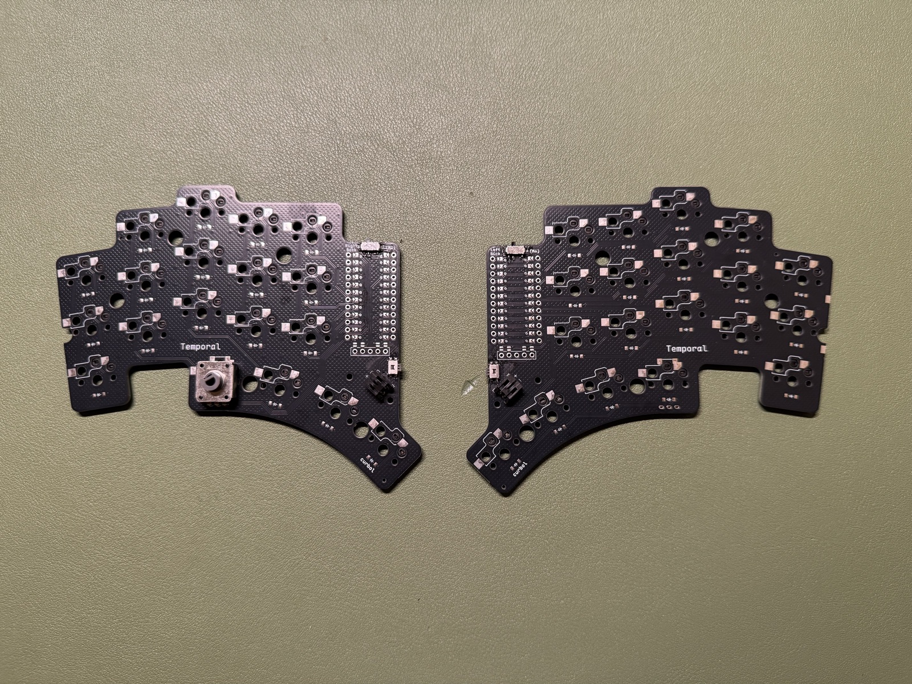
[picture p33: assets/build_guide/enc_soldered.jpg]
Encoder soldered


### Encoders with Switch Function

If your encoder has a push-button switch (5 pins total instead of 3):

1. The 3 encoder pins are soldered through-hole as described above
2. The 2 switch pins need to be **surface mounted** on the front of the PCB
3. Bend and trim the switch pins so they can lay flat on the SMD pads
4. Solder the switch pins to the SMD pads on the front

---

## Step 5: Install the Microcontroller

### nice!nano Installation

1. Insert the mill-max pins into the sockets (not into the nice!nano yet)
2. Place the nice!nano **face down** (components facing the PCB) onto the pins
3. Solder the pins to the nice!nano

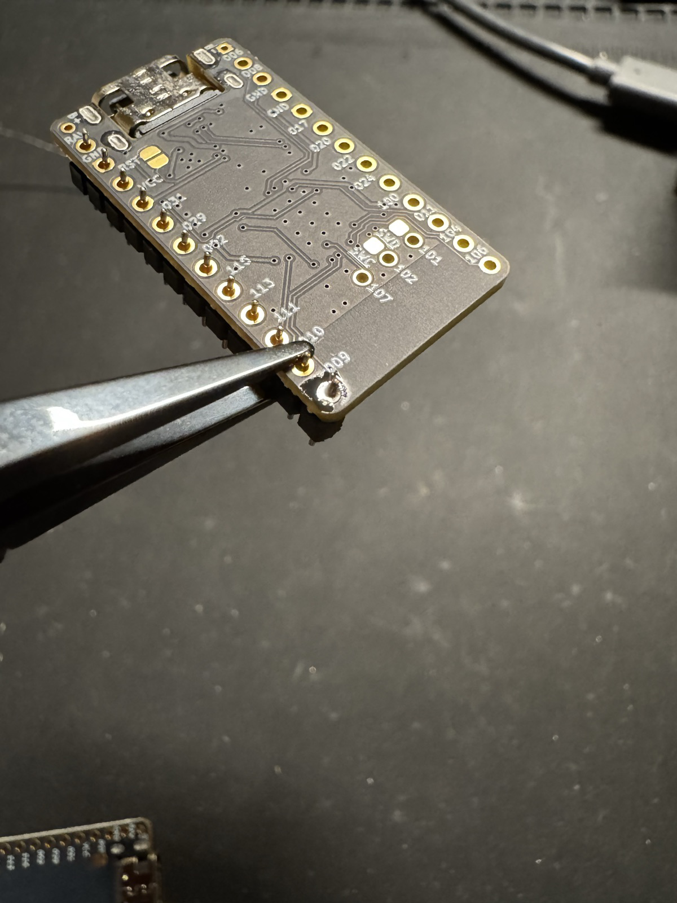
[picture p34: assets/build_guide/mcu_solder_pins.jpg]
MCU socket pins soldered


4. The nice!nano should now be removable from the sockets

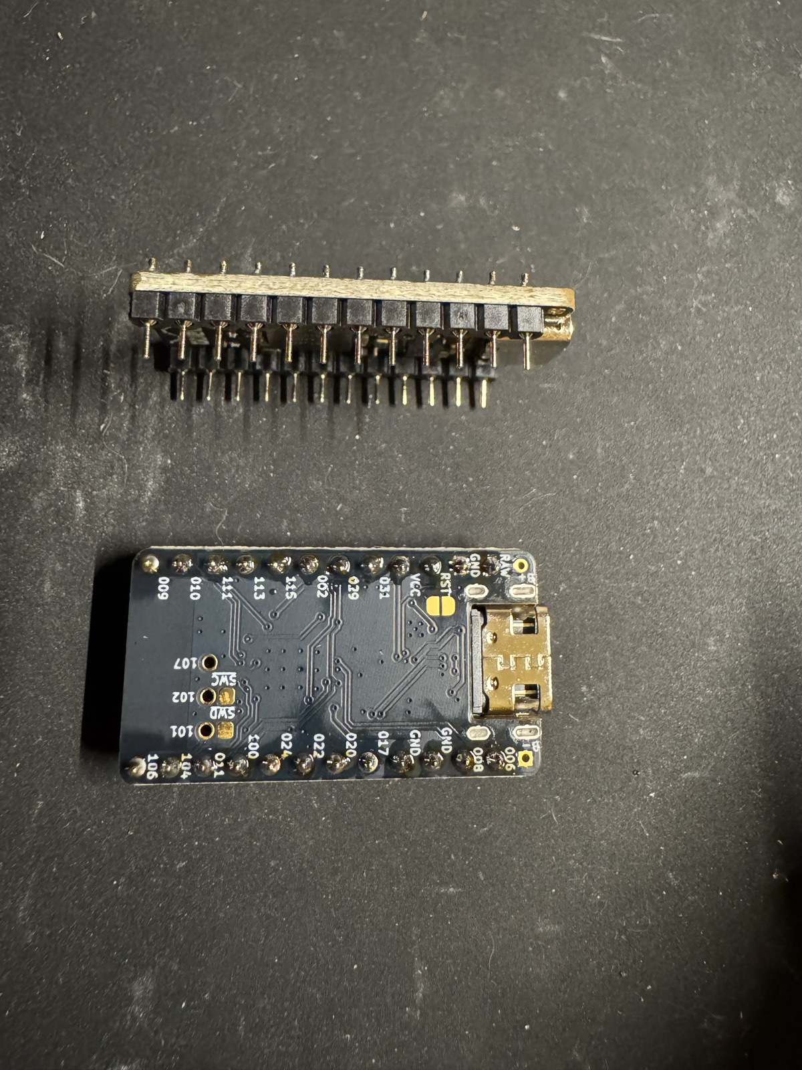
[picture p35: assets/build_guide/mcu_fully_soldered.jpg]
MCU fully soldered


### Display Installation (Optional)

If using a nice!view or other display:

1. Insert pins into the display header
2. Place the display onto the pins
3. Solder and trim

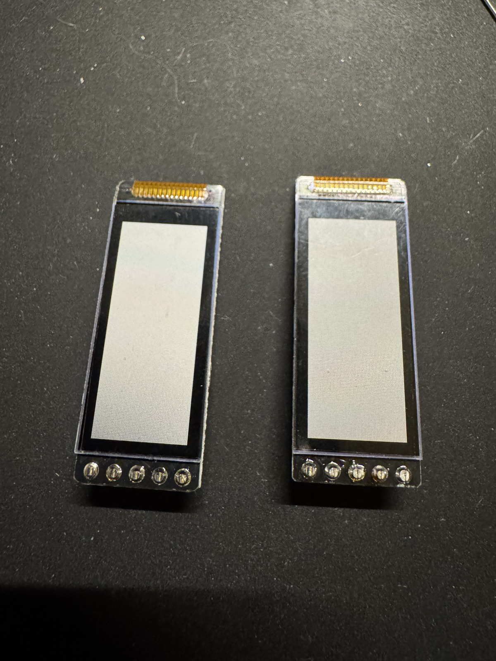
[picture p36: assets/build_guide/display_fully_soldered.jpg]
Display fully soldered


### Clean the PCB

After all soldering is complete, clean the board to remove flux residue. Flux left on the PCB can be corrosive over time and looks untidy.

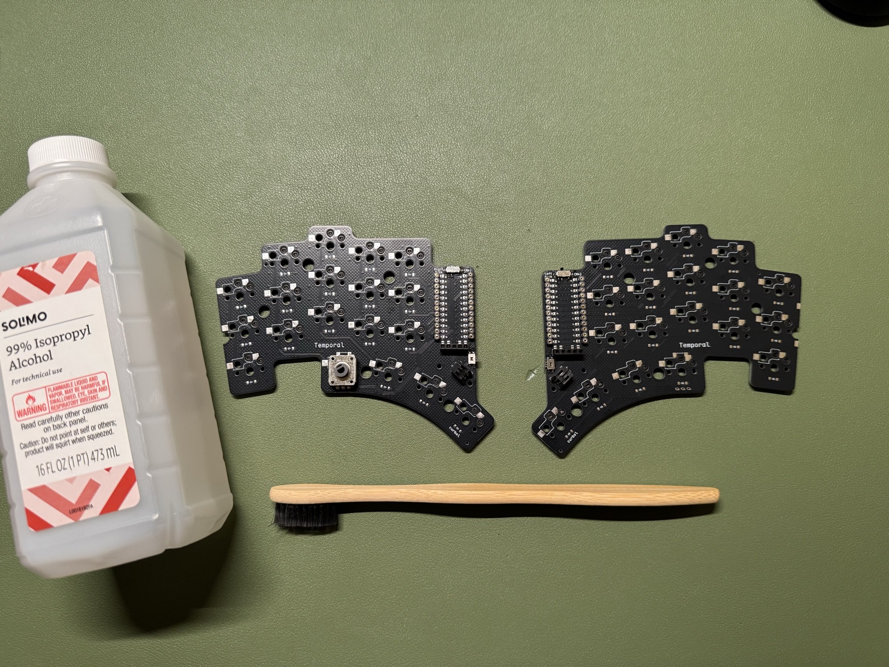
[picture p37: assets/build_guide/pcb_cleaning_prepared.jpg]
PCB cleaning prepared


1. Dip a toothbrush in isopropyl alcohol (90% or higher works best)
2. Scrub all solder joints thoroughly
3. Allow the board to dry completely before powering on

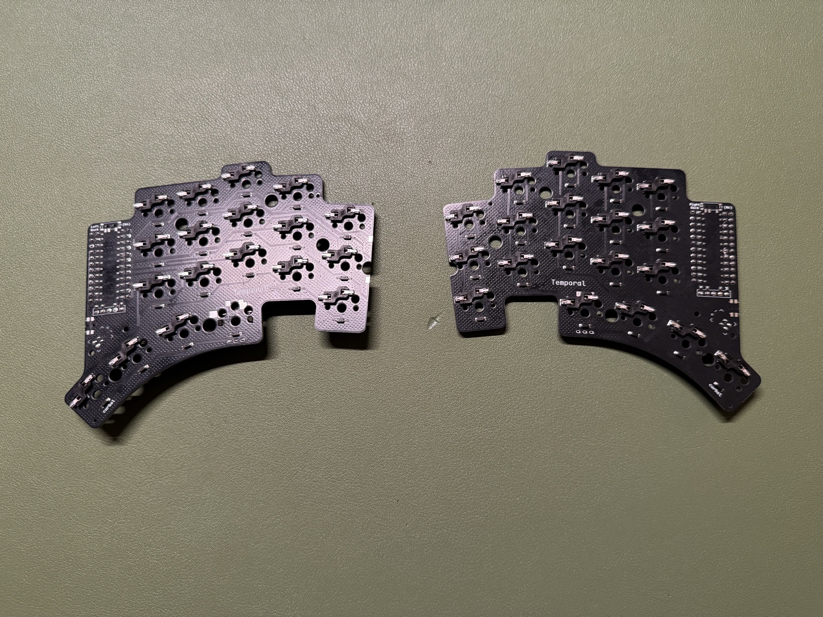
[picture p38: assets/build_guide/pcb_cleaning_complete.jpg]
PCB cleaning complete


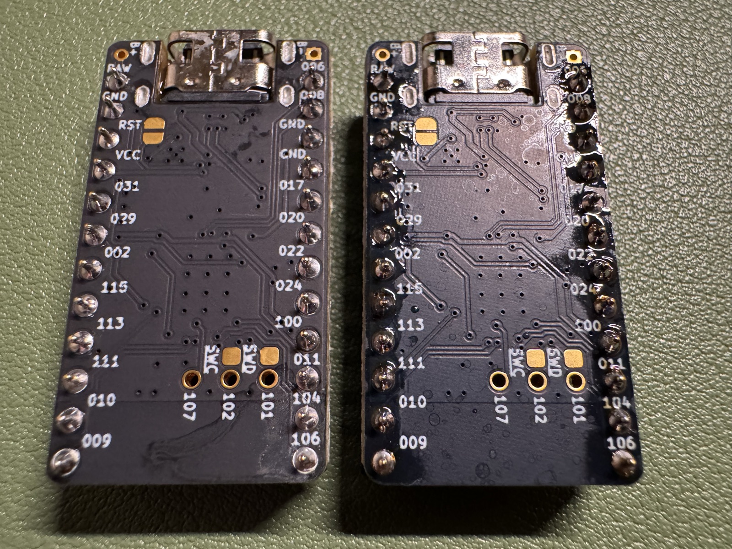
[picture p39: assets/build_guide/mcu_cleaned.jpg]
MCU area cleaned

*Left: after cleaning. Right: before cleaning.*

---

## Step 6: Case Assembly

### MCU Cover

1. Attach the MCU cover using 8mm standoffs
2. Use 2 M2 screws (4mm length) from the back of the PCB into the standoffs
3. Use 2 more M2 screws (4mm length) from the front through the cover into the standoffs

### 3D-Printed Case

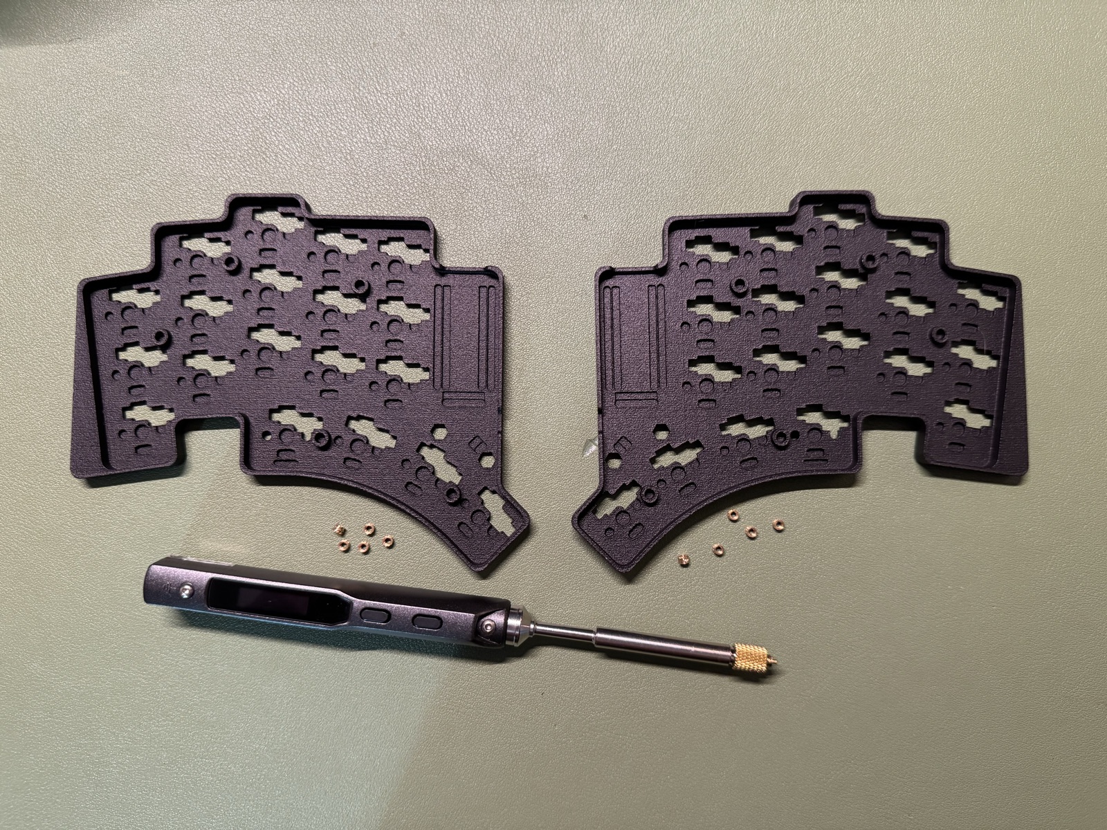
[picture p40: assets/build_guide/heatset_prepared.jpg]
Heat-set inserts prepared


1. Install 5 heat-set inserts into the case posts with a soldering iron or heat-set tool

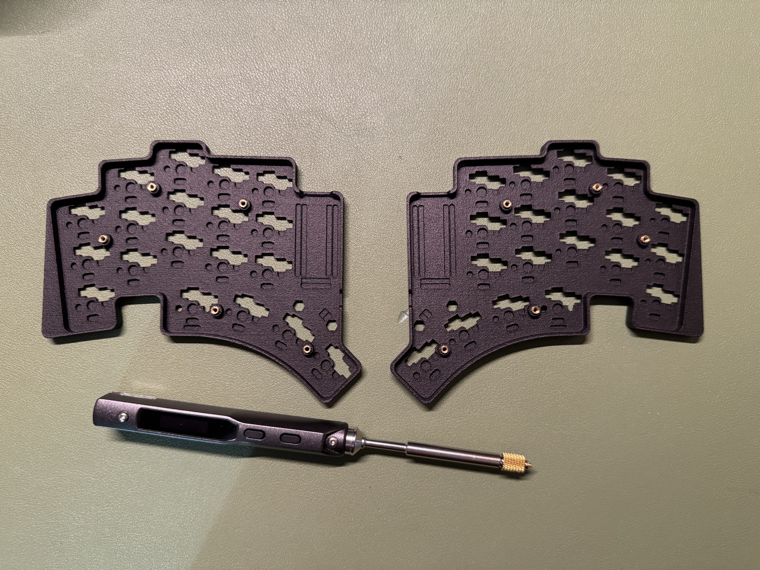
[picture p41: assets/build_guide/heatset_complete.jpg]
Heat-set inserts installed


2. Place the PCB into the case; the case posts go through its mounting holes

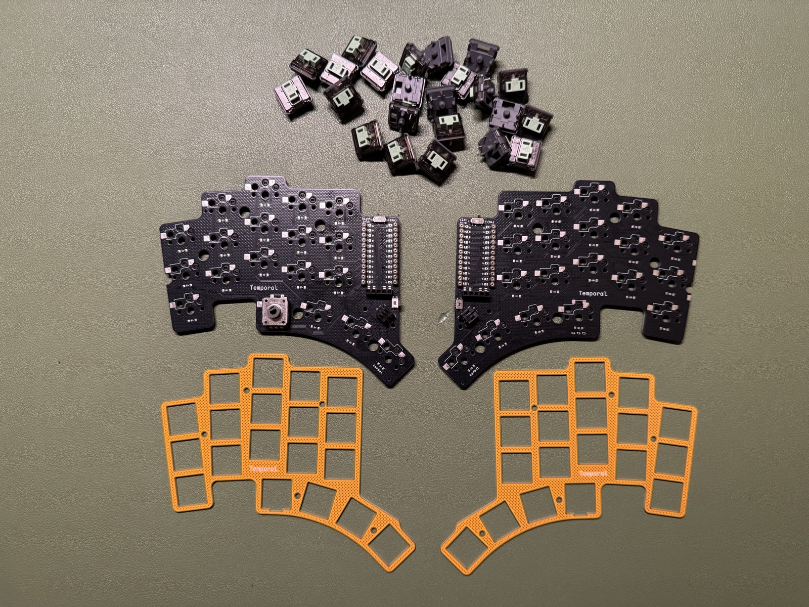
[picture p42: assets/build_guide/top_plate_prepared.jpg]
Top plate prepared


3. Place the top plate over the PCB, aligning with the case posts

> [!TIP]
> Insert a few switches into the top plate before placing it on the PCB. This helps maintain proper spacing and alignment.

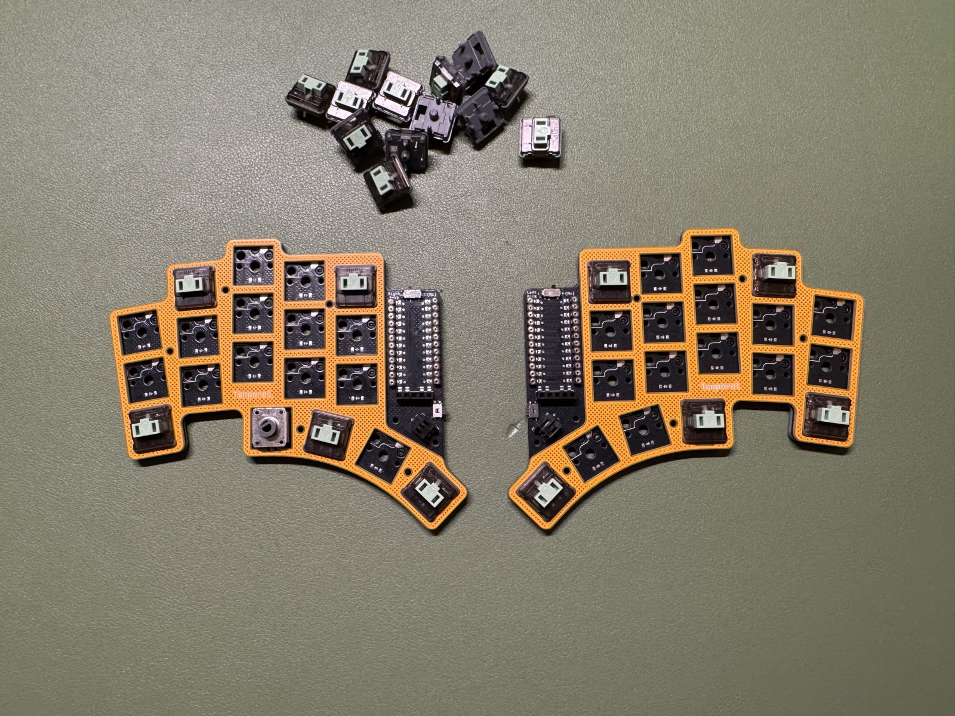
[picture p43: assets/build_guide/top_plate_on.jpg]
Top plate installed


4. Secure with M2 screws (4mm length) through the top plate into the heat-set inserts

### FR-4 Plate Alternative

If using FR-4 plates instead of a 3D-printed case:

1. Attach the back plate using 3mm standoffs, which clear the 1.95mm hotswap sockets on the back of the PCB
2. Secure with M2 screws (3mm length) from both faces; longer screws meet inside a 3mm standoff and bottom out
3. Add the top plate and seat the switches through it into the hotswap sockets

---

## Step 7: Switches and Keycaps

1. Insert Choc v1 or v2 switches into the top plate
2. Press firmly until the switches click into the hotswap sockets
3. Install keycaps onto the switches
4. If using encoders, press the knobs onto the encoder shafts

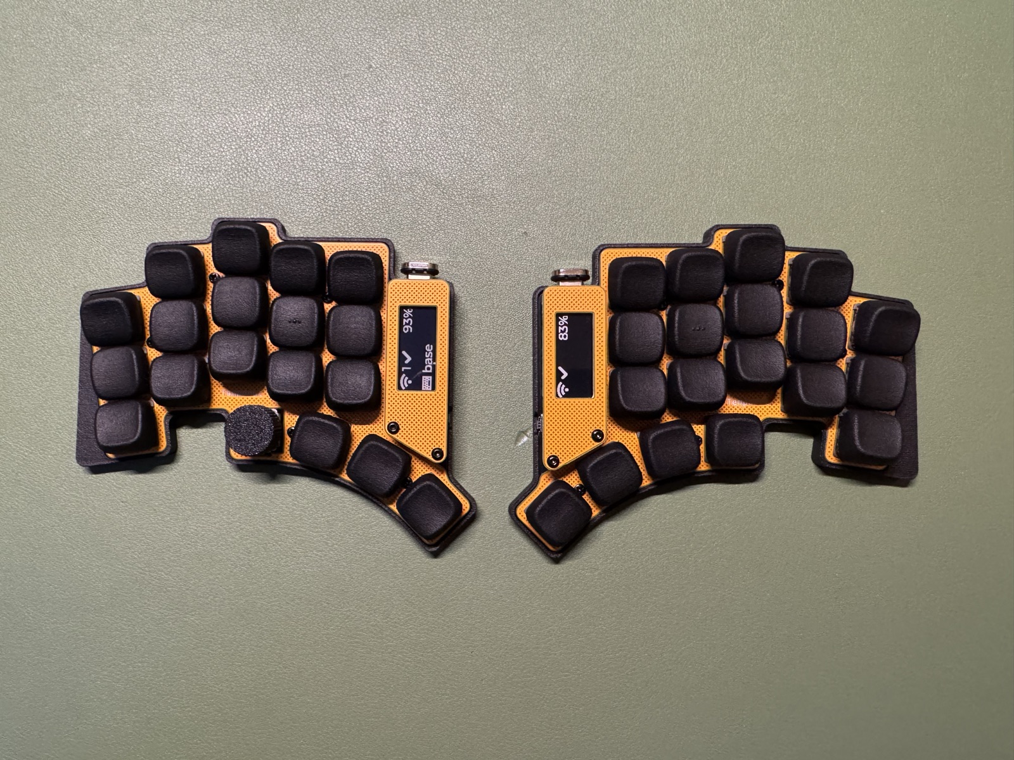
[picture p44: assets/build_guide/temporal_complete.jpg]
Temporal keyboard complete


---

## Flashing Firmware

Temporal runs ZMK.

### Initial Setup

1. Create a ZMK config repository by following the [ZMK User Setup Guide](https://zmk.dev/docs/user-setup)
2. Add [temporal-zmk](https://github.com/curbol/temporal-zmk) to `config/west.yml` as a shield module ([example](https://github.com/curbol/zmk-config/blob/main/config/west.yml))
3. List both halves in `build.yaml` ([example](https://github.com/curbol/zmk-config/blob/main/build.yaml))
4. [curbol/zmk-config](https://github.com/curbol/zmk-config/tree/main/config) shows the whole config together

### Keymap Editor (Optional)

[Keymap Editor](https://nickcoutsos.github.io/keymap-editor/) edits the keymap visually. Point it at the layout from [temporal-zmk](https://github.com/curbol/temporal-zmk).

### Flashing the Firmware

1. Push your config changes to GitHub
2. The GitHub Action builds the firmware automatically
3. Download the firmware artifact from the Actions tab
4. Extract the zip; it holds two `.uf2` files, one per half

### Entering Bootloader Mode

1. Double-click the reset button on the PCB
2. The nice!nano will appear as a USB drive on your computer

### Flash Each Half

1. Drag the `temporal_left-nice_nano_v2-zmk.uf2` file to the left half's drive
2. Repeat for the right half with `temporal_right-nice_nano_v2-zmk.uf2`

> [!NOTE]
> You must flash both halves on first setup. After initial pairing, keymap changes typically only require flashing the left half.

---

## Additional Resources

- [Typeractive's Corne build guide](https://docs.typeractive.xyz/build-guides/corne-wireless): a close reference for wireless split builds
- [ZMK documentation](https://zmk.dev/docs)
- [temporal-zmk](https://github.com/curbol/temporal-zmk): the ZMK shield module for this board

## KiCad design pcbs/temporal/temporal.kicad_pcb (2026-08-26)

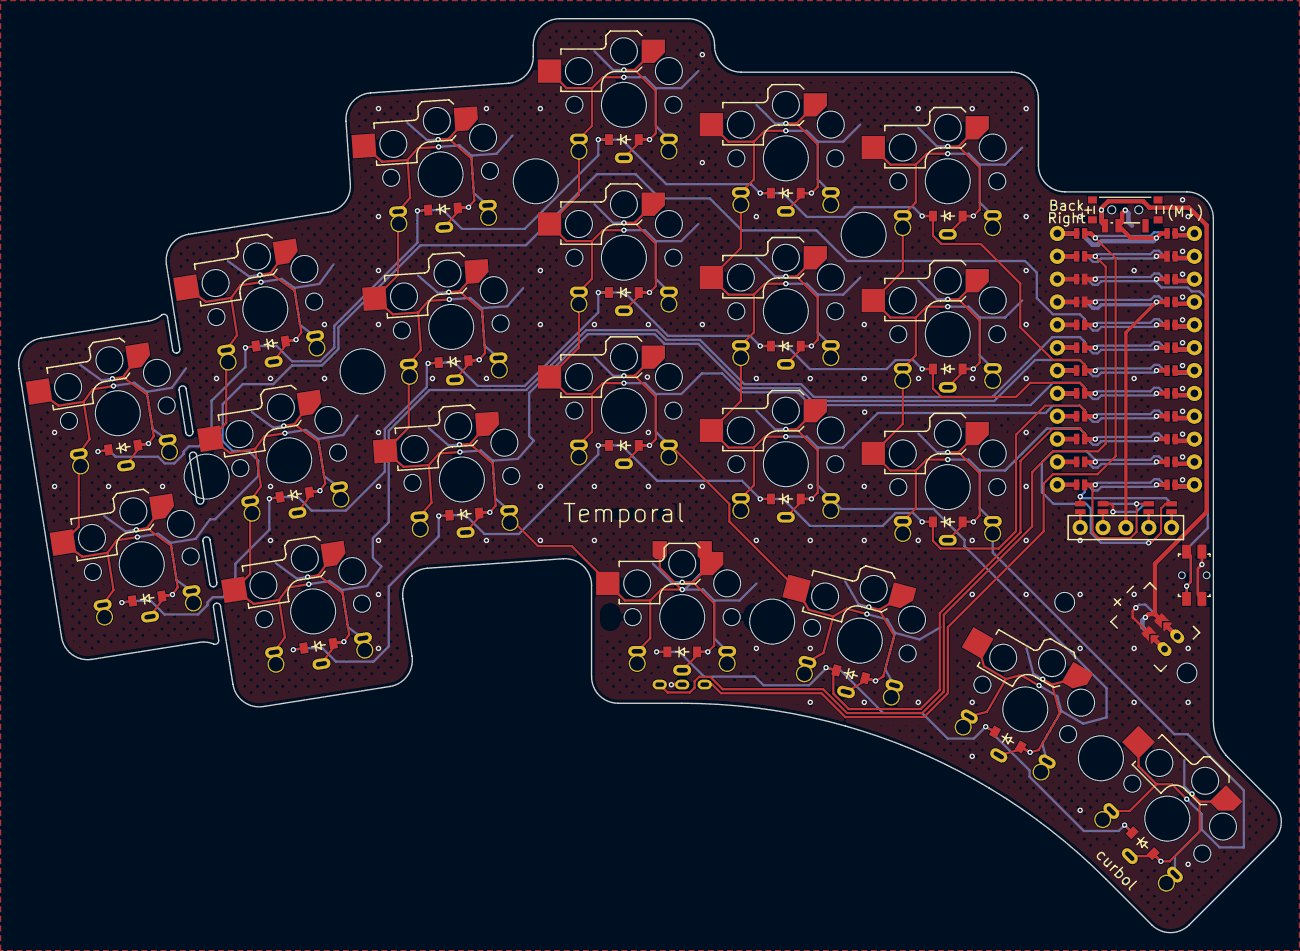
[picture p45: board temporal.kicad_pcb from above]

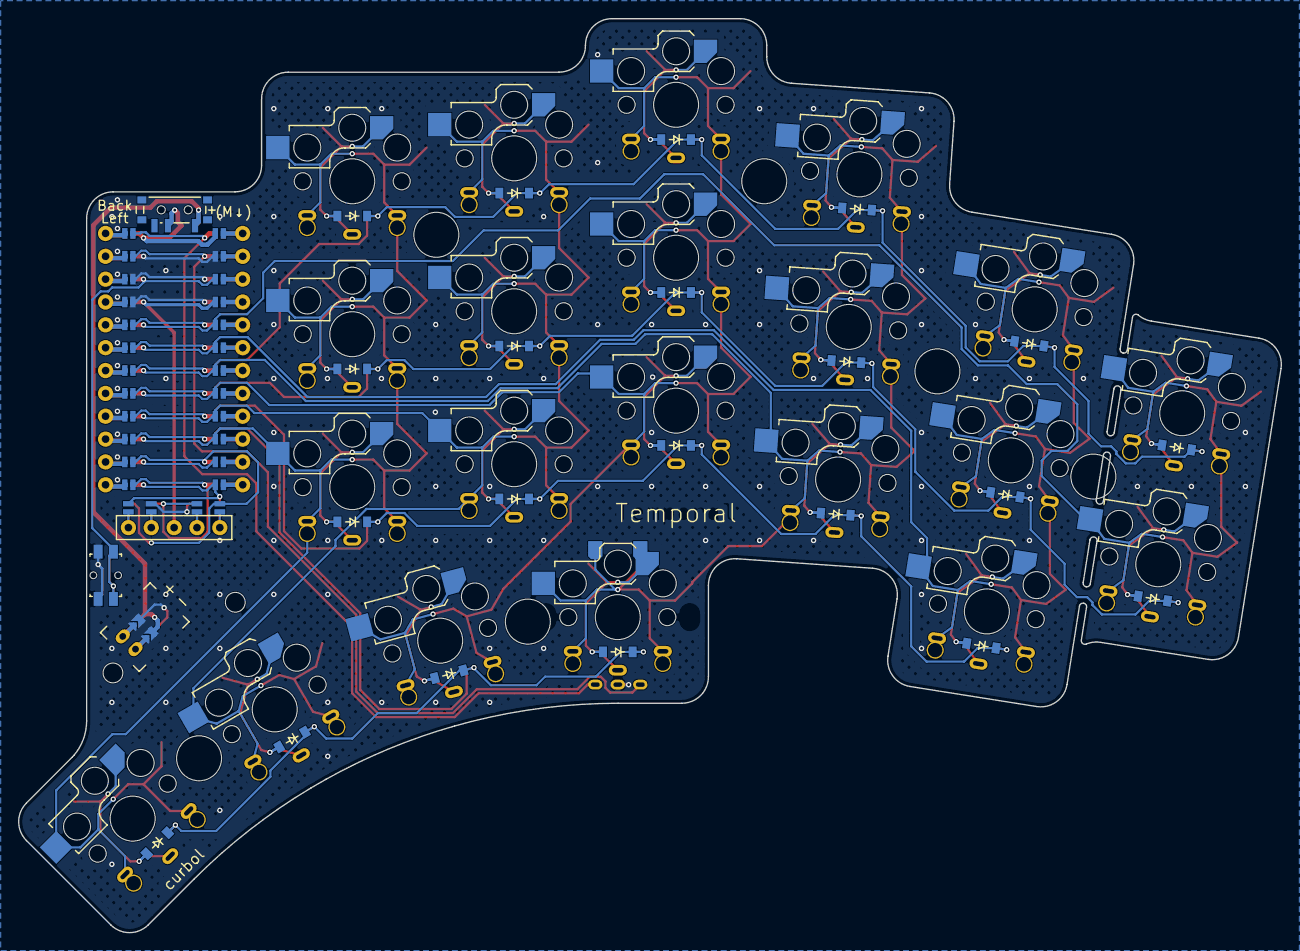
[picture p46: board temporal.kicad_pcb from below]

Board: 2 copper layers, 140.4 x 101.6 mm, 56 parts (21 on the bottom side), 47 nets.

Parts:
D1, D2, D3, D4, D5, D6, D7, D8, D9, D10, D11, D12, D13, D14, D15, D16, D17, D18, D19, D20, D21: diode_tht_sod123
DISP1: display_nice_view
JST1: battery_connector_jst_ph_2
MCU1: mcu_nice_nano
MH1, MH2, MH3, MH4, MH5, MH6, MH7, MH8: mounting_hole_npth
PWR1: power_switch_smd_side
RE1: rotary_encoder_ec11_ec12
RST1: reset_switch_smd_side
S1, S2, S3, S4, S5, S6, S7, S8, S9, S10, S11, S12, S13, S14, S15, S16, S17, S18, S19, S20, S21: switch_choc_v1_v2

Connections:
BAT_P: JST1.1, PWR1.1, PWR1.3
CS: DISP1.14, DISP1.24, MCU1.112
DISP1_1: DISP1.1, DISP1.10, DISP1.23
DISP1_2: DISP1.2, DISP1.11, DISP1.22
DISP1_4: DISP1.4, DISP1.12, DISP1.21
DISP1_5: DISP1.5, DISP1.13, DISP1.20
GND: DISP1.15, DISP1.25, JST1.2, MCU1.102, MCU1.121, MCU1.122, RE1.C, RST1.1, RST1.3
JST1_1: JST1.11, JST1.21, JST1.31
JST1_2: JST1.12, JST1.22, JST1.32
MOSI: DISP1.17, DISP1.27, MCU1.114
RAW: MCU1.101, PWR1.2
RST: MCU1.103, RST1.2, RST1.4
SCK: DISP1.16, DISP1.26, MCU1.113
VCC: DISP1.3, MCU1.104
col_extra: MCU1.105, S1.1, S1.2, S2.1, S2.2
col_index: MCU1.109, S12.1, S12.2, S13.1, S13.2, S14.1, S14.2, S20.1, S20.2
col_inner: MCU1.110, S15.1, S15.2, S16.1, S16.2, S17.1, S17.2, S21.1, S21.2
col_middle: MCU1.108, S9.1, S9.2, S10.1, S10.2, S11.1, S11.2, S19.1, S19.2
col_pinky: MCU1.106, S3.1, S3.2, S4.1, S4.2, S5.1, S5.2
col_ring: MCU1.107, RE1.S1, S6.1, S6.2, S7.1, S7.2, S8.1, S8.2, S18.1, S18.2
enc_thumb: D18.2, RE1.S2, S18.1, S18.2
encoder_a: MCU1.123, RE1.A
encoder_b: MCU1.124, RE1.B
extra_home: D1.2, S1.1, S1.2
extra_top: D2.2, S2.1, S2.2
far_thumb: D21.2, S21.1, S21.2
index_bottom: D12.2, S12.1, S12.2
index_home: D13.2, S13.1, S13.2
index_top: D14.2, S14.1, S14.2
inner_bottom: D15.2, S15.1, S15.2
inner_home: D16.2, S16.1, S16.2
inner_top: D17.2, S17.1, S17.2
mid_thumb: D20.2, S20.1, S20.2
middle_bottom: D9.2, S9.1, S9.2
middle_home: D10.2, S10.1, S10.2
middle_top: D11.2, S11.1, S11.2
near_thumb: D19.2, S19.1, S19.2
pinky_bottom: D3.2, S3.1, S3.2
pinky_home: D4.2, S4.1, S4.2
pinky_top: D5.2, S5.1, S5.2
ring_bottom: D6.2, S6.1, S6.2
ring_home: D7.2, S7.1, S7.2
ring_top: D8.2, S8.1, S8.2
row_bottom: D3.1, D6.1, D9.1, D12.1, D15.1, MCU1.116
row_home: D1.1, D4.1, D7.1, D10.1, D13.1, D16.1, MCU1.117
row_thumb: D18.1, D19.1, D20.1, D21.1, MCU1.115
row_top: D2.1, D5.1, D8.1, D11.1, D14.1, D17.1, MCU1.118

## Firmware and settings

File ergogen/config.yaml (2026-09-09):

# Temporal, by Curtis Bollinger - @curbol
# https://github.com/curbol/temporal
# v1 - Sep 2026
#
# Key configurations: 36-42 keys depending on breakoffs and encoders
#   - Full pinky column: 42/41/40 keys (0/1/2 encoders)
#   - Breakoff pinky column: 38/37/36 keys (0/1/2 encoders)
#
# Case naming convention:
#   - _left: Left-hand side case (generated directly)
#   - _m_right: Right-hand side case (needs to be mirrored after ergogen generation)

# ergogen docs: https://docs.ergogen.xyz/config-overview

meta:
  engine: 4.1.0
  version: 1.0
  author: Curtis Bollinger
  url: https://github.com/curbol/temporal

# ============================================================================
# Units
# ============================================================================
units:
  # Math constants
  sqrt_3: 1.73205080757
  nudge: 0.0001 # Hack used to fix floating point rounding issues

  # Override choc defaults
  $default_width: 18
  $default_height: 17

  # Key spacing with padding
  pad: 2.151
  px: cx + pad
  py: cy + pad

  # Key plug holes
  plug_w: 13.9
  plug_h: 13.9

  # Finger splay
  finger_splay_1: 5
  finger_splay_2: 4
  finger_splay_total: finger_splay_1 + finger_splay_2
  thumb_splay: 15
  thumb_spread: 1cx - 0.15

  # Board dimensions
  pcb_fillet: 2.95
  pcb_thickness: 1.6
  pcb_hole_diameter: 5

  # Copper geometry. scripts/kicad_config.js fills these into the net classes and
  # the via-stitching parameters, so they are typed here and nowhere else.
  copper_trace_width: 0.25
  copper_power_trace_width: 0.375
  copper_battery_trace_width: 0.5
  copper_via_diameter: 0.6
  copper_via_drill: 0.3

  # Silkscreen stroke width. JLCPCB's minimum is 0.153mm (6 mil), and this is the
  # pen KiCad strokes the glyph outlines with, so anything thinner is flagged at
  # upload and prints faint.
  silk_line_width: 0.16

  # Mounting hole positions (relative to key centers)
  hole1_x: -0.5cx - 0.8 # Top left (finger_middle_top)
  hole1_y: -0.5cy
  hole2_x: 0.5cx - 0.35 # Top right (finger_index_top)
  hole2_y: -0.5cy
  hole3_x: 0.5cx + 1 # Thumb right (thumb_mid)
  hole3_y: -0.5
  hole4_x: 0.5cx + 1 # Thumb left (thumb_enc)
  hole4_y: -0.5
  hole5_x: 0.5cx + 0.6 # Far left (finger_pinky_top)
  hole5_y: -0.5cy
  hole5_e_x: 0.5cx - 0.35 # Far left extra (finger_extra_top)
  hole5_e_y: -0.5cy

  # MCU positioning (relative to finger_inner_home)
  mcu_y: -12.3
  mcu_x: 19.8
  mcu_area_w: 19.45
  mcu_area_h: 56.25
  mcu_pin_spacing: 7.62

  # Display positioning
  display_x: mcu_x
  display_y: 6.75 + mcu_y
  display_origin_y: display_y + 0.75 # nice!view draws its screen 0.75mm off its origin
  display_w: 11.3
  display_h: 25.8

  # Component positions
  power_x: mcu_x - 0.07
  power_y: 26.1 + mcu_y
  reset_x: 27.4
  reset_y: -14.5 + mcu_y
  battery_x: 24.8
  battery_y: -22 + mcu_y
  battery_rot: -135

  # MCU Cover holes (relative to finger_inner_bottom)
  mcu_hole1_x: 0.5cx + 4
  mcu_hole1_y: -0.5cy + mcu_y + 8
  mcu_hole2_x: 0.5cx + 17.6
  mcu_hole2_y: -0.5cy + mcu_y + 0.146

  # Breakoff tab
  break_cut_w: 0.8
  break_cut_fillet: break_cut_w / 2 - nudge
  break_bridge_size: 3.7

  # Choc
  choc_under_to_pcb: 2.2
  choc_top_plate: 1.3
  choc_post_d: 2.65
  choc_center_post_w: 3.4
  choc_side_post_w: 1.9
  choc_side_post_x: 5.5 # Matches choc_v1_stabilizers in the vendored switch footprint

  # Choc v2 (Kailh PG1353, part CPG135301D01). A v2 switch keeps the v1 side
  # bosses and adds a wider, deeper centre boss plus one corner stabilizer pin, so
  # these clearances are additional to the v1 ones rather than replacing them.
  choc_v2_center_post_w: 4.8 # Datasheet Ø4.80 centre boss
  choc_v2_post_d: 3.3 # Datasheet 3.30 protrusion below the switch base
  choc_v2_stab_w: 1.6 # The stabilizer pin's hole in the PCB
  choc_v2_stab_x: 5 # Corner stabilizer, mirrored per hand
  choc_v2_stab_y: -5.15

  # Direct-solder switch pins. Each relief is a stadium, two circles and the bar
  # between them, and its width is what the bridges to the diode and the stabilizer
  # pocket span.
  solder_pin_r: 1
  solder_pin_dx: 0.25
  solder_pin_w: 2 * (solder_pin_dx + solder_pin_r)
  solder_mid_y: -5.9
  solder_side_x: 5
  solder_side_y: -3.8

  # Hotswap socket relief. The rest of the outline is traced in place, but the two block
  # edges nearest the switch are named because the v2 centre pocket bridges to them.
  socket_block_x: 2.15 # Bottom block, edge nearest the switch centre
  socket_block_y: 1.15 # Bottom block, lower edge
  socket_top_block_y: 3.35 # Top block, lower edge
  socket_block_top_y: socket_block_y + 5.4 # Bottom block, upper edge

  # Diode
  diode_y: -3.864
  diode_d: 1.15
  diode_pads_w: 3.85
  diode_pads_h: 0.6
  diode_w: 2.7
  diode_h: 1.65
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

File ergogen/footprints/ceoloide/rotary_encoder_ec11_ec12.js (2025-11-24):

/*
Copyright (c) 2023 Marco Massarelli

SPDX-License-Identifier: MIT

To view a copy of this license, visit https://opensource.org/license/mit/

Author: @ceoloide

Description:
  Reversible Alps EC11 / EC12 rotary encoder footprint with customization options to make it
  compatible with Cherry MX or Choc v1 / v2 footprints, when co-located.
  
  The Alps EC12 (EC12E2440301) has a short through-shaft model that is well suited for low
  profile keyboards, although it doesn't include a momentary switch.

Notes:
- The footprint can be co-located with a Cherry MX hotswap footprint, as long as the outermost
  hotswap pads are at most 2 mm tall, so that they won't overlap with the plate mount legs
  of the rotary encoder. The encoder mounting pads can be positioned 7.5mm instead of 5.6mm to
  avoid overlap with mounting pins.
- The footprint can be co-located with a Choc v1 / v2 hotswap footprint, as long as the encoder
  pads are positioned at least 8.254 mm. If Choc v1 is co-located with the encoder, then mounting
  pads can be positioned 8.00mm instead of 5.6mm to avoid overlap with mounting pins. Choc v2
  don't have those pins, so wouldn't need the encoder mounting pads moved.
- The footprint is inherently reversible, no solder jumper needed. Make sure to invert the pin
  assignment for pad A and C in firmware, to ensure the encoder rotation is handled consistently.

Datasheet:
  https://www.soundwell.hk/ec12-rotary-encoder.html

Params:
  side: default is F for Front
    the side on which to place the single-side footprint and designator, either F or B
  reversible: default is false
    if true, the footprint silkscreen will be placed on both sides so that the PCB can be
    reversible. Pads are all THT, and only A and C need to be reversed in software.
  include_momentary_switch_pads: default is true
    if true, the footprint will include 2 extra pads to accommodate for momentary switch pins,
    normally found in EC11-compatible rotary encoders.
  include_plate_hole_marking: default is false
    if true, will add a shape to indicate plate hole size and position for the encoder. If the
    encoder is co-located with a switch, then the regular 14mm plate hole will be slightly
    larger and work well enough.
  include_silkscreen: default is true
    if true it will include the silkscreen.
  include_plated_mounting_holes: default is true
    If true, it will include plated mounting holes and their pads, instead of just mechanical
    NPTH for the mounting pins. The advantage of NPTH is that they can be more easily co-located
    with Cherry MX mounting pins, allowing the Cherry MX hotswap pads to be 2.3 mm tall instead of
    2.0 mmm.
  mounting_holes_position: default is 5.6 (mm)
    The distance in mm from the center of the footprint where to position the side mounting
    pads. The datasheet calls for 5.7mm, but wider position can be accommodated by bending
    legs slightly, while clearing up space for switch mounting pins (i.e. 7.5mm for Cherry,
    8mm for Choc v1, see notes).
  mounting_hole_width: default is 1.5 (mm)
    The width of the mounting holes, in mm. The datasheet calls for 1.4mm rectangular, so an
    extra mm is added for the oval shape. Note that the plated pad is made 0.3mm larger.
  mounting_hole_height: default is 2.3 (mm)
    The height of the mounting holes, in mm. The datasheet calls for 2.1mm rectangular, but users
    reported a very tight fit with 2.1 mm oval holes, so the default is slightly larger. If the
    footprint is not co-located with hotswap sockets, then 2.8 mm is a safe default, as it is the
    same value used in the Sofle and other keyboards. Note that the plated pad is made 0.3mm larger.
  encoder_pads_position: default is 7.5 (mm)
    The position of the encoder pads, in mm. The datasheet calls for 7.5mm, but this makes it
    impossible for the encoder to be co-located wtih Choc v1 / v2 hotswap pads, as it would overlap.
    Increasing the value will require the encoder pins to be slightly bent. For Choc v1 / v2 use 
    8.254 as a minimum.
  encoder_3dmodel_filename: default is ''
    Allows you to specify the path to a 3D model STEP or WRL file to be
    used when rendering the PCB. Use the ${VAR_NAME} syntax to point to
    a KiCad configured path.
  encoder_3dmodel_xyz_offset: default is [0, 0, 0]
    xyz offset (in mm), used to adjust the position of the 3d model
    relative the footprint.
  encoder_3dmodel_xyz_scale: default is [1, 1, 1]
    xyz scale, used to adjust the size of the 3d model relative to its
    original size.
  encoder_3dmodel_xyz_rotation: default is [0, 0, 0]
    xyz rotation (in degrees), used to adjust the orientation of the 3d
    model relative the footprint.
*/
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

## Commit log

2025-11-24 temporal keyboard
    [back_plate_38.kicad_pcb, back_plate_40.kicad_pcb, back_plate_42.kicad_pcb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]
2025-11-24 create image for all pcbs
    [back_plate_38.kicad_pcb, back_plate_40.kicad_pcb, back_plate_42.kicad_pcb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]
2025-11-24 update reset footprint
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2025-11-25 update gen files
    [back_plate_38.kicad_pcb, back_plate_40.kicad_pcb, back_plate_42.kicad_pcb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]
2025-11-25 fix plate holes
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2025-11-26 update pcbs
    [mcu_cover.kicad_pcb, top_plate_38.kicad_pcb, top_plate_40.kicad_pcb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]
2025-11-26 kicad config fixes
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2025-11-27 fix trace from diode to hotswap
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2025-11-29 update hole4
    [top_plate_38.stl, top_plate_40.stl, top_plate_42.stl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]
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2025-11-29 move up TEMPORAL text
    [mcu_cover.kicad_pcb, top_plate_38.kicad_pcb, top_plate_40.kicad_pcb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]
2025-11-30 add bom and cpl generation
    [temporal_BOM.csv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]
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2025-12-13 swap power and reset
    [config.yaml]
2025-12-13 update naming and gen files
    [mcu_cover.kicad_pcb, mcu_cover.stl, top_plate_38.kicad_pcb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]
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2025-12-15 fix case kickstand depth
    [config.yaml]
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2025-12-23 fix encoder net
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2025-12-26 remove sockets from jlcpcb bom
    jlcpcb is not able to add hotswap sockets.
2025-12-26 remove sockets for JLC PCBA
    [temporal_BOM.csv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]
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2025-12-28 Update BOM with additional hardware details
    Added hardware components required per keyboard half.
2025-12-28 Change source link for M2 Heat Set Inserts
    Updated source link for M2 Heat Set Inserts.
2025-12-28 Remove No-Solder Spring Headers from BOM
    Removed No-Solder Spring Headers entry from tools list.
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2026-01-12 add resistor pads for jumpers
    [back_plate_40.kicad_pcb, mcu_cover.kicad_pcb, temporal_BOM.csv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]
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2026-01-13 add 0ohm resistors (jumpers) to bom and cpl
    [temporal_BOM.csv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]
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2026-01-14 rename to correct keycounts
    [back_plate_38.kicad_pcb, back_plate_40.kicad_pcb, mcu_cover.kicad_pcb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]
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2026-01-17 use admesh instead of openscad
    [mirror_case.scad]
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2026-01-20 update catch
    [temporal_socket_38_kickstand_left.stl, temporal_socket_38_kickstand_right.stl, temporal_socket_38_left.stl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]
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2026-01-23 add stealth top-plates
    [top_plate_38_stealth.kicad_pcb, top_plate_42_stealth.kicad_pcb]
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2026-01-26 fix jlcpcb bottom generation
    [temporal_CPL_bottom.csv]
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2026-08-24 Add choc v2 support, KiCad 10 compatibility, and solid via zone connections
    - Union choc v1/v2 switch footprint with reworked S11 trace topology
    - Fix three KiCad 9->10 API breaks (zone fill setter rename, board
    outline signature, lexicographic Version() comparison that silently
    produced zero stitching vias)
    - Add custom DRC rules (.kicad_dru) forcing solid zone connections for
    vias, clearing 5 copper slivers and 2 dangling vias
    - Enlarge Temporal and MCU silkscreen text so substituted font weights
    meet the thickness minimum
    - Make `make deps` work on Linux; patch xmldom vulnerability via override
    Claude-Session: https://claude.a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
    [back_plate_38.kicad_pcb, back_plate_42.kicad_pcb, mcu_cover.kicad_pcb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]
2026-08-25 Make the build verifiable and the silkscreen host-independent
    Adds `make check` as the repo's automated verification, run by a new CI
    workflow: sources parse, ESLint is clean, ergogen/config.yaml builds, every
    committed board passes DRC and carries its own silkscreen font, the pours in
    pcbs/ still match the custom DRC rules, and temporal.json and jlcpcb/ reproduce
    from their sources. The reproducibility step compares against a temp-dir
    snapshot rather than git state, so it runs on a dirty tree instead of skipping.
    Silkscreen no longer depends on the exporting machine. The weight-suffixed font
    faces ("Maple Mono NF ExtraBold", "Maple Mono NF Medium") never resolved, since
    every Maple Mono fi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
    [back_plate_38.kicad_pcb, back_plate_42.kicad_pcb, mcu_cover.kicad_pcb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]
2026-08-25 Refresh audit command for the current build pipeline
    The repo picked up eslint, a check.yml CI job, a make check target, seven new
    scripts and two shared config modules since the command was written, so most of
    its line references pointed at code that had moved and its baseline block
    hand-rolled checks that make check now encodes.
    Replace the baseline with make check, re-anchor every path and line reference,
    and add invariants for the config-module ownership rule and for silkscreen
    uniformity plus embedded fonts. Drop the criteria the linter now decides and
    the findings the code has since fixed. Enabling eslint's recommended set
    produces no additional errors today, so the automation guidanc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
2026-08-25 Derive shared dimensions from units and close the artifact-check gaps
    Fixes from a full-repo audit. Three groups.
    Geometry, in ergogen/config.yaml:
    - The encoder's mounting slots defaulted to 5.6mm from centre, overlapping the
    Choc v1 side boss holes at 5.5mm on thumb_enc. The two NPTH holes merged into
    one ~1.9x2.3mm opening, which JLCPCB flags and which lets whichever part is
    populated rock in the axis its footprint meant to constrain. KiCad reports no
    hole_to_hole or holes_co_located violation for it at any severity, so nothing
    caught it. Now 8mm, the value rotary_encoder_ec11_ec12.js recommends when Choc
    v1 mounting pins share the key.
    - M2 clearance holes on the MCU cover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
    [back_plate_38.kicad_pcb, back_plate_42.kicad_pcb, mcu_cover.kicad_pcb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]
2026-08-25 Add Choc v2 case clearances for the centre boss and stabilizer pin
    Dimensions from the Kailh PG1353 datasheet (CPG135301D01): the v2 centre boss is
    Ø4.80 and protrudes 3.30mm below the switch base, and the switch adds one corner
    stabilizer pin, which the footprint already drills at (±5, 5.15) with a 1.6mm hole.
    Neither had any case clearance.
    The new outlines are named _choc_v2_* and are subtracted alongside the v1 cutouts
    rather than folded into them, so one case still takes either switch:
    - _choc_v2_center_post, through the floor. The boss reaches
    choc_v2_post_d - pcb_thickness + buffer = 1.8mm below the board, into a
    bottom_thickness of 1.95mm; the 0.15mm that would be left is not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
    [back_plate_38.kicad_pcb, back_plate_42.kicad_pcb, mcu_cover.kicad_pcb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]
2026-08-25 Split cases by Choc generation and export binary STL
    bottom_thickness is the hotswap socket height, and the socket relief is cut
    through the floor, so at 1.95 the socket bottom finishes flush with the case
    bottom. Raising the floor to give the v2 centre boss a blind pocket would sink
    every socket by the difference and lose the flat bottom, and covering a socket
    outright would need 2.45. So the floor stays, the v2 pocket stays a through
    hole, and a v1 build gets its own case rather than a hole under every key for a
    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
    [mcu_cover.stl, temporal_socket_38_kickstand_left.stl, temporal_socket_38_kickstand_right.stl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]
2026-08-25 Restore hand routing onto the regenerated temporal board
    pcbs/temporal was regenerated to pick up the Choc v2 config work, which drops the
    hand routing with it. This puts the routing back on the new board: 1213 segments
    and 217 vias, an exact element-for-element match to the routed copy, on footprints
    that now carry the moved encoder mounting slots, the Ø2.2 MCU holes, and none of
    the 16 dead display resistor pads.
    The via set is taken wholesale rather than merged. Diffing the two boards showed
    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
    [back_plate_38.kicad_pcb, back_plate_42.kicad_pcb, mcu_cover.kicad_pcb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]
2026-08-26 Fold case STLs into per-variant folders and set silkscreen bold
    Four strands, all verified together by make check.
    Silkscreen is now bold. KiCad reaches a heavier Maple Mono only through the
    bold attribute, since a weight-suffixed family name resolves to nothing, so
    utility_text takes bold and mcu_nice_nano and power_switch_smd_side take
    label_font_bold. Boards embed MapleMono-NF-Bold.ttf, and the text_thickness
    warnings drop from 14 to 9 because the bold outlines carry more of the pen.
    Case STLs are foldered rather than flat. Case keys now read in the order a
    builder decides, temporal_<38|42>_<v1|v2>_<socket|solder>[_kickstand]_<hand>,
    and convert_jscad.js maps that to cases/<count>/<gene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
    [back_plate_38.kicad_pcb, back_plate_42.kicad_pcb, kickstand_left.stl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]
2026-08-26 Remove four redundant track fragments from the temporal routing
    Four spots on the hand routing carried a fragment sitting on a via with no
    electrical purpose. Two shapes, handled differently:
    Two were end-to-end joints, a short segment continuing straight out of a longer
    one, replaced by a single segment between the outer endpoints. Both are
    axis-aligned and the merged length equals the sum of the originals exactly
    (0.0399 + 1.2000 = 1.2399 on row_top, 0.2199 + 1.3350 = 1.5549 on BAT_P), so no
    copper moved and no angle changed.
    Two were duplicates rather than joints: a short segment lying entirely on top of
    a longer one, both ending at the same via at (217.4199, 166.0235), one per
    layer. M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
    [temporal.kicad_pcb]
2026-08-26 Install the tooling CI needs and give pcbnew a display
    The kicad/kicad:10.0 image carries KiCad and python3 but no make or
    unzip, so every run died at exit 127 before reaching the check. Behind
    that, check_zone_fills.py builds a wx.App to load a board, which needs a
    display even though nothing is drawn.
    Claude-Session: https://claude.ai/code/session_01DKErAEZKMvhHXQyGoYuzBo
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2026-09-07 Make the post-processing passes fail loudly instead of silently
    KiCad's bundled pcbnew.py iterates its containers by calling next() on the
    SWIG iterator, which newer SWIG builds expose only as __next__. On Python
    3.14 that breaks GetDrawings() in the text keepout pass and the iteration
    inside the ViaStitching plugin, so `make gen` cannot get past step 2. Both
    scripts now alias next to __next__ when it is missing, a no-op where it
    already exists.
    The rest closes gaps where a pass could do the wrong thing without saying
    so: a keepout group holding no zone no longer counts as protecting its
    text, the ViaStitching plugin directory is picked by version rather than
    lexicographically so 10.0 outra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
2026-09-07 Fold the four case variants into one and give the floor a solid bottom
    The Choc v2 boss pocket and the hotswap socket relief overlap in plan, and
    both cut through the 1.95mm floor, so where their boundaries cross the
    leftover material tapers to a knife edge standing the full height of the
    floor with nothing under it. No clearance setting fixes that: with the
    padding stripped off both, the real Ø4.8 boss and the real socket body are
    0.515mm apart, so even at zero clearance there is no wall to be had.
    Stop cutting through instead. bottom_thickness becomes socket_depth +
    floor_skin, 2.35mm, and every pocket in the floor is blind: socket relief
    and encoder legs at 1.95, the v2 boss and its sta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
    [back_plate_38.kicad_pcb, back_plate_42.kicad_pcb, kickstand_left.stl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]
2026-09-07 Cut the v2 boss bridge to the pocket radius so its wall has no step
    The bridge was sized to reach a fixed clearance into the socket's bottom
    block, socket_block_x + cutout_padding, which is 2.75mm against a pocket
    radius of 2.70. Below the bottom block nothing covers that 0.05mm, so the
    overhang printed as a step partway down the pocket wall.
    One radius wide instead. The edge now leaves the circle tangentially, so
    the wall runs straight up out of the arc, and it still lands 0.55mm inside
    the bottom block, which is all the bridge needs to join the two pockets.
    Sub-0.4mm material at that junction measures 0.0381 mm² against 0.0394 for
    the wider version, and the socket-depth floor loses the 1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
    [back_plate_38.kicad_pcb, back_plate_42.kicad_pcb, kickstand_left.stl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]
2026-09-07 Narrow the stabilizer bridge so it stays inside the pocket boundary
    The side solder relief and the v2 stabilizer pocket cross at 81 degrees,
    which is near enough to a right angle that their union boundary is already
    smooth. A bridge two pocket-widths across cuts straight over that boundary
    and bulges 0.18mm out of it at the waist, printing as a step on both sides.
    Take the pin hole's width instead of the pocket's, choc_v2_stab_w rather
    than choc_v2_stab_w + cutout_padding. That keeps the edge inside the union
    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
    [back_plate_38.kicad_pcb, back_plate_42.kicad_pcb, kickstand_left.stl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]
2026-09-08 Cut every floor pocket in a single subtraction
    Ergogen's JSCAD backend is a BSP kernel, so each subtraction splits the
    floor polygon along the cutter's wall planes extended clear across the
    board and leaves reversed coplanar fragments on the cut boundaries. The
    half-cases ran ten of those in sequence against one shell, re-splitting
    the floor plane ten times and accumulating inverted-normal geometry that
    z-fights the real floor in any viewer.
    Union the cutters into one solid per half-case and subtract that once.
    The right hands carried 416 mm2 (38) and 407 mm2 (42) of inverted
    coverage at the floor plane, 9-13 mm2 of which was the only surface
    covering that floor at all. All four hands now m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
    [kickstand_left.stl, kickstand_right.stl, left.stl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]
2026-09-08 Cut the M2 bores to insert depth and widen the v2 diode bridge
    The insert bore was subtracted inside _posts_*, so unioning the shell
    back on refilled everything below the floor line. Every bore came out
    2.5mm deep with 2.35mm of solid floor under it, and m2_insert_hole_depth
    had no effect at any value above the post height. A 3mm heat-set insert
    was going into a 2.5mm blind hole, seating only because it melted the
    last half-millimetre. Cut it with the other floor pockets instead, and
    size it off the insert: a 3.5mm bore leaving 1.35mm of floor beneath.
    That retires the trick where _posts_42 re-added _posts_pinky to refill
    hole 5. The two hole sets are named outright now, _post_holes_core fo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
    [back_plate_38.kicad_pcb, back_plate_42.kicad_pcb, kickstand_left.stl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]
2026-09-08 Fail the build steps whose patterns stopped matching
    Several passes reported success on an empty result, so a rename or an
    upstream change could ship a wrong board with every gate still green.
    generate_jlcpcb_files.js rejects a configured footprint name matching
    nothing. Renaming an assembly part or a jumper parent used to drop that
    whole class from the BOM while the other class kept the output non-empty;
    make check would then call the files stale and tell you to commit them.
    create_text_keepouts.py returns per-pattern hit counts so its wrapper can
    fail a keepout pattern that matched no text on any board. The text lives
    in ergogen/config.yaml and the pattern in kicad_config.yaml with nothi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
2026-09-08 Point the build guide at cases/ for the MCU cover
    The flowchart listed mcu_cover.stl under cases/NN/, but convert_jscad
    matches neither of its variant patterns for that name, so it lands at the
    top of cases/. docs/bom.md and cases/README.md both had it right.
    Claude-Session: https://claude.ai/code/session_012nHFSP7xyYogVPyRfCNgSY
2026-09-08 Drop the unified case design spec now that it has shipped
    The design it worked out landed in 33bd75d and the bridge commits after
    it: one case carrying every switch and mounting clearance at once, with a
    floor of socket_depth plus a skin so each pocket stays blind. What a
    builder needs from it lives in cases/README.md and docs/bom.md.
    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
2026-09-08 Refresh the audit command against the folded case config
    The line ranges, board counts and scope list had drifted since the four
    case variants became one. Updates the config section boundaries, adds
    cases/README.md and the doc photo directories, names
    copy_pcb_if_missing.sh as the producer of pcbs/temporal/README.md, and
    narrows the accepted text_thickness warnings to the three boards that
    actually carry silkscreen text.
    Also swaps the post-processing violation shape from an error path that
    logs and continues to a step reporting success on an empty input set,
    which is the failure the passes are now written to avoid.
    Claude-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
2026-09-08 Widen the v2 diode bridge to the diode pocket
    At the boss width its edge stopped at x=1.2 while the diode pocket runs
    to 1.65, leaving a wedge of floor trapped between the boss circle above,
    the bridge edge to one side and the diode pocket below: 0.32mm tall and
    under half a millimetre thick, thinner than one extrusion.
    Taking the diode pocket's own width makes the two side edges collinear,
    so the union has one straight wall from the boss pocket down past the
    diode and the wedge is gone. Going further, to the diode pad relief,
    does not work: that relief is cut at pin depth, so matching its width
    cuts diode depth where the shelf ends and leaves it standing 0.65mm
    proud beside every key.
    Co-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
    [back_plate_38.kicad_pcb, back_plate_42.kicad_pcb, kickstand_left.stl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]
2026-09-08 Refresh the audit command against this session's changes
    Every line anchor in the command was re-verified against the tree, and
    `make check` was run to confirm the baseline block still holds.
    Retire the two criteria whose defects have since been fixed: the
    add_ground_planes tri-state return and the setup_kicad_project empty
    glob. Restate invariant 4's blind-pocket rule as a depth budget, since
    the M2 bore now deliberately cuts 1mm into the floor rather than
    stopping at it.
    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
2026-09-08 Ignore the exporter's build string when comparing gerbers
    The check re-exports every board and diffs it against the committed zip,
    dropping the lines that record who exported and when. It missed one. The
    .gbr and .drl files name the KiCad build on a GenerationSoftware line,
    which the filter already caught, but the .gbrjob is JSON: GenerationSoftware
    is an object header there and the build sits a level in, on a "Version" line
    of its own that survived the filter.
    That line is the only difference left between an export from KiCad 10.0.5
    and one from the 10.0.5-1-g226df246f3 rebuild, verified by diffing two
    exports of an unchanged temporal.kicad_pcb. So regenerating the gerbers on
    a rebuilt loc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
2026-09-09 Share one silkscreen layer test across the passes that read it
    Three spellings of the layer token reach these passes: pcbnew writes
    (layer "F.SilkS"), Ergogen writes it with a trailing space, and
    utility_text adds a knockout modifier. fix_silkscreen_width matched only
    the first by exact substring, and its residual-stroke backstop called the
    same predicate, so both halves of its self-check would miss a stroke
    together. create_stealth_variants accepted two of the three.
    A knockout silkscreen text would have survived the stealth pass while its
    own post-condition counted zero, and make check would still pass, since a
    board with no face left is skipped before the embedded-font assertion.
    Also a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
2026-09-09 Check the zone settings the fill check cannot see
    check_zone_fills refills each board in memory and compares the filled
    area, and its docstring claimed that covered the zones: settings. It
    cannot: add_ground_planes writes those values into the (zone ...) block
    itself, so refilling reads them back off the board and the area comes out
    unchanged by construction. Only the custom DRC rules move it.
    So an edit to zones: reached every disposable board on the next run and
    left pcbs/temporal on the old pour, silently, since the fills and the
    derived artifacts all still reproduced.
    check_zone_settings compares each pour's own parameters against the
    config and fails when it finds no pour at all, so a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
2026-09-09 Patch FillArea with a script instead of BSD-incompatible sed
    make deps rewrote two clearance calculations in the ViaStitching plugin
    using sed with \n in the replacement. GNU sed turns that into a newline;
    BSD sed, which macOS ships, writes a literal n. The result was a file
    that still contained both marker strings and no longer parsed.
    Both verifications were defeated by that, because both looked for the
    marker text rather than a working file: the grep in deps reported the
    patches verified, and via_stitching.py never reached its own check,
    since the SyntaxError from importing FillArea is not an ImportError.
    So make deps succeeded and make gen died later with a raw traceback.
    patch_fill_ar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
2026-09-09 Fail instead of writing the wrong thing quietly
    embed_fonts.js took any path on argv and passed it to embed_fonts.py,
    which saves through pcbnew, truncates the file to rewrite it as text, and
    saves again. Nothing stopped that reaching pcbs/temporal, whose routing
    cannot be regenerated, and make check's font assertion names board paths,
    so pointing the script at one is the obvious response to it. Paths now
    have to resolve inside ergogen/output/pcbs.
    convert_jscad.js fell through to <name>.stl for a case name neither
    regex matched, landing it at the top of cases/ instead of in its count
    folder, with make gen still reporting success. Shared parts are named
    now, and anything else is an error.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
2026-09-09 Tie the via clearances to via_size and fix a pre-KiCad-7 call
    units.copper_via_diameter is where CLAUDE.md says via geometry is typed,
    but it cannot actually be raised. switch_choc_v1_v2 bounds via_separation
    to 3 * via_size - 0.25 .. 2.25 - via_size, which at 0.6 is a 0.1mm window
    the config sits in the middle of and which closes entirely above 0.63.
    mcu_nice_nano put its GND vias 0.55mm off the row and shifted the right
    side trace 0.2mm the other way, leaving exactly the 0.2mm net class
    clearance and no margin; the offset now comes from via_size.
    The choc via checks also ran before the branch that emits a via, so the
    footprint's own declared defaults threw on any board that did not copy
    v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
2026-09-09 Stop claiming JLCPCB cannot place hotswap sockets
    Kailh's CPG135001S30 is C5333465 in JLCPCB's assembly parts library,
    flagged for SMT assembly, so the reason the note gave was wrong. The
    part is Standard assembly only and JLCPCB wants a fixture for it, which
    is a cost, not an impossibility.
    What is true is that the sockets are not in the generated files, and
    adding them is not a kicad_config.yaml edit: they have no footprint of
    their own, and their pads are x-mirrored between the faces, so the
    centroid moves. Every part in the CPL today sits on its parent's origin
    or comes in symmetric pairs, which is why generate_jlcpcb_files.js can
    serve both hands from one set of coordinates.
    Co-Author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
2026-09-09 Make the MCU jumper pockets an exact mirror pair
    _mcu_jumpers_trench carried its own -0.025 y offset, and the second
    instance adds rotate: 180, which flipped that offset rather than
    cancelling it. The two trenches ended up 0.05mm apart in y: the left
    spanned -16.05..13.50 and the right -16.00..13.55.
    Both hands share this pocket, so one hand's jumper pads sat 0.05mm
    nearer the trench end than the other's. Moving the offset onto the two
    instance shifts makes the pair an exact x-mirror and raises the
    tightest clearance around the MCU pads from 0.128mm to 0.150mm on both
    hands.
    Claude-Session: https://claude.ai/code/session_01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
    [back_plate_38.kicad_pcb, back_plate_42.kicad_pcb, kickstand_left.stl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]

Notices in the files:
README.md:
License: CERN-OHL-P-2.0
